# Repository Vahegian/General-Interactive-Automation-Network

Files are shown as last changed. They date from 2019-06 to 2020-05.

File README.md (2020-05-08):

#### Project was moved here from university GitLab.

### General Interactive automation network

With growing number of Internet of Things “IoT” devices almost everything in our homes and offices can be automated or controlled remotely. 
The General Interactive Automation Network “GIAN” is a system that is trying to achieve just that. GIAN uses simple gesture based commands to select and operate devices. Now the system is connected to a robot, which can be operated by user with two simple hand gestures. In the future 5G network can be used to connect 100s of devices to the system, which will allow it to do more complex tasks such as decorating a house or simply kipping it tidy. The system is developed with scalability in mind to allow fast expansion. It currently works with 3 programming languages giving it access to large number of libraries that can be used for connecting to devices running on Python, Java or C++. 
GIAN is not only taking user inputs, it also provides feedback on what it thinks a user is trying to do. Currently the feedback is provided via Java GUI application on PC and LED matrix in real world. 

## [Video](https://cseegit.essex.ac.uk/ce301/grigoryan_v/capstone_project/blob/master/general-intereractive-automation-network/The%20Project/Research%20and%20Files/Files/Genera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) explaining how everything comes together

For more details about developed code and setup process click [here](https://github.com/Vahegian/General-Interactive-Automation-Network/blob/master/The%20Project/Research%20and%20Files/Papers/Final%20Report.pdf)

## This is what I am working on now.


## The System Flow.
<p align="center"> 
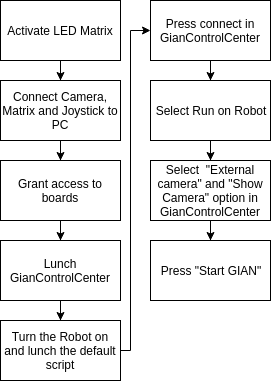
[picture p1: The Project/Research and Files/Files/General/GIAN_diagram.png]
	 
</p>

## The robot selection
<p align="center">
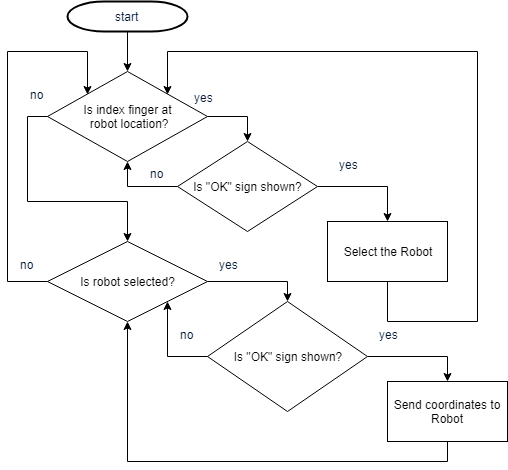
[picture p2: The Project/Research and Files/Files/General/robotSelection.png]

</p>

### INFO

This directory contains two folders. 

"[Summer Research](https://cseegit.essex.ac.uk/ce301/grigoryan_v/capstone_project/tree/master/general-intereractive-automation-network/Summer%20Research)" folder contains files and papers that have been used to come up with a plan for this project. 

"[The Project](https://cseegit.essex.ac.uk/ce301/grigoryan_v/capstone_project/tree/master/general-intereractive-automation-network/The%20Project)" folder contains files and code that are being developed for completing the task.

Most directories will have corresponding "README" files to describe the content of the folder and/or how to use their content. 

## Shortcuts to important directories  

#	1. [3d Models](https://github.com/Vahegian/General-Interactive-Automation-Network/tree/master/The%20Project/Research%20and%20Files/Files/Matrix/3D%20Models)

#	2. [Robot](https://github.com/Vahegian/General-Interactive-Automation-Network/tree/master/The%20Project/JAVA)

#	3. [Arduino](https://github.com/Vahegian/General-Interactive-Automation-Network/tree/master/The%20Project/c%5Cc%2B%2B)

#	4. ['CNN' and master control](https://github.com/Vahegian/General-Interactive-Automation-Network/tree/master/The%20Project/Python)

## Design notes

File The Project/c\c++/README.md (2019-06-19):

### INFO

Master folder contains Arduino script that receives coordinates from pc through Serial communication and transmits them to other 3 Arduinos via I2C communication, also it controls the LEDs of the first matrix. 

The other 3 folders contain Arduino scripts that receive coordinates with I2C and control the LEDs if the coordinates are in the range that they are programmed to control.

Use Arduino IDE to install code on arduino boards. If computer can't access the boards run "arduinopermitions.sh" in linux terminal and try again.

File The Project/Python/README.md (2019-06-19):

## Main Python code is located in "GIAN_files" folder.

## Intro

 

Real-time object detection and classification. Paper: [version 1](https://arxiv.org/pdf/1506.02640.pdf), [version 2](https://arxiv.org/pdf/1612.08242.pdf).

Read more about YOLO (in darknet) and download weight files [here](http://pjreddie.com/darknet/yolo/). In case the weight file cannot be found, I uploaded some of mine [here](https://drive.google.com/drive/folders/0B1tW_VtY7onidEwyQ2FtQVplWEU), which include `yolo-full` and `yolo-tiny` of v1.0, `tiny-yolo-v1.1` of v1.1 and `yolo`, `tiny-yolo-voc` of v2.

See demo below or see on [this imgur](http://i.imgur.com/EyZZKAA.gif)



## Dependencies

Python3, tensorflow 1.0, numpy, opencv 3.

### Getting started

You can choose _one_ of the following three ways to get started with darkflow.

1. Just build the Cython extensions in place. NOTE: If installing this way you will have to use `./flow` in the cloned darkflow directory instead of `flow` as darkflow is not installed globally.
    ```
    python3 setup.py build_ext --inplace
    ```

2. Let pip install darkflow globally in dev mode (still globally accessible, but changes to the code immediately take effect)
    ```
    pip install -e .
    ```

3. Install with pip globally
    ```
    pip install .
    ```

## Update

**Android demo on Tensorflow's** [here](https://github.com/tensorflow/tensorflow/blob/master/tensorflow/examples/android/src/org/tensorflow/demo/TensorFlowYoloDetector.java)

**I am looking for help:**
 - `help wanted` labels in issue track

## Parsing the annotations

Skip this if you are not training or fine-tuning anything (you simply want to forward flow a trained net)

For example, if you want to work with only 3 classes `tvmonitor`, `person`, `pottedplant`; edit `labels.txt` as follows

```
tvmonitor
person
pottedplant
```

And that's it. `darkflow` will take care of the rest. You can also set darkflow to load from a custom labels file with the `--labels` flag (i.e. `--labels myOtherLabelsFile.txt`). This can be helpful when working with multiple models with different sets of output labels. When this flag is not set, darkflow will load from `labels.txt` by default (unless you are using one of the recognized `.cfg` files designed for the COCO or VOC dataset - then the labels file will be ignored and the COCO or VOC labels will be loaded).

## Design the net

Skip this if you are working with one of the original configurations since they are already there. Otherwise, see the following example:

```python
...

[convolutional]
batch_normalize = 1
size = 3
stride = 1
pad = 1
activation = leaky

[maxpool]

[connected]
output = 4096
activation = linear

...
```

## Flowing the graph using `flow`

```bash
# Have a look at its options
flow --h
```

First, let's take a closer look at one of a very useful option `--load`

```bash
# 1. Load tiny-yolo.weights
flow --model cfg/tiny-yolo.cfg --load bin/tiny-yolo.weights

# 2. To completely initialize a model, leave the --load option
flow --model cfg/yolo-new.cfg

# 3. It is useful to reuse the first identical layers of tiny for `yolo-new`
flow --model cfg/yolo-new.cfg --load bin/tiny-yolo.weights
# this will print out which layers are reused, which are initialized
```

All input images from default folder `sample_img/` are flowed through the net and predictions are put in `sample_img/out/`. We can always specify more parameters for such forward passes, such as detection threshold, batch size, images folder, etc.

```bash
# Forward all images in sample_img/ using tiny yolo and 100% GPU usage
flow --imgdir sample_img/ --model cfg/tiny-yolo.cfg --load bin/tiny-yolo.weights --gpu 1.0
```
json output can be generated with descriptions of the pixel location of each bounding box and the pixel location. Each prediction is stored in the `sample_img/out` folder by default. An example json array is shown below.
```bash
# Forward all images in sample_img/ using tiny yolo and JSON output.
flow --imgdir sample_img/ --model cfg/tiny-yolo.cfg --load bin/tiny-yolo.weights --json
```
JSON output:
```json
[{"label":"person", "confidence": 0.56, "topleft": {"x": 184, "y": 101}, "bottomright": {"x": 274, "y": 382}},
{"label": "dog", "confidence": 0.32, "topleft": {"x": 71, "y": 263}, "bottomright": {"x": 193, "y": 353}},
{"label": "horse", "confidence": 0.76, "topleft": {"x": 412, "y": 109}, "bottomright": {"x": 592,"y": 337}}]
```
 - label: self explanatory
 - confidence: somewhere between 0 and 1 (how confident yolo is about that detection)
 - topleft: pixel coordinate of top left corner of box.
 - bottomright: pixel coordinate of bottom right corner of box.

## Training new model

Training is simple as you only have to add option `--train`. Training set and annotation will be parsed if this is the first time a new configuration is trained. To point to training set and annotations, use option `--dataset` and `--annotation`. A few examples:

```bash
# Initialize yolo-new from yolo-tiny, then train the net on 100% GPU:
flow --model cfg/yolo-new.cfg --load bin/tiny-yolo.weights --train --gpu 1.0

# Completely initialize yolo-new and train it with ADAM optimizer
flow --model cfg/yolo-new.cfg --train --trainer adam
```

During training, the script will occasionally save intermediate results into Tensorflow checkpoints, stored in `ckpt/`. To resume to any checkpoint before performing training/testing, use `--load [checkpoint_num]` option, if `checkpoint_num < 0`, `darkflow` will load the most recent save by parsing `ckpt/checkpoint`.

```bash
# Resume the most recent checkpoint for training
flow --train --model cfg/yolo-new.cfg --load -1

# Test with checkpoint at step 1500
flow --model cfg/yolo-new.cfg --load 1500

# Fine tuning yolo-tiny from the original one
flow --train --model cfg/tiny-yolo.cfg --load bin/tiny-yolo.weights
```

Example of training on Pascal VOC 2007:
```bash
# Download the Pascal VOC dataset:
curl -O https://pjreddie.com/media/files/VOCtest_06-Nov-2007.tar
tar xf VOCtest_06-Nov-2007.tar

# An example of the Pascal VOC annotation format:
vim VOCdevkit/VOC2007/Annotations/000001.xml

# Train the net on the Pascal dataset:
flow --model cfg/yolo-new.cfg --train --dataset "~/VOCdevkit/VOC2007/JPEGImages" --annotation "~/VOCdevkit/VOC2007/Annotations"
```

### Training on your own dataset

*The steps below assume we want to use tiny YOLO and our dataset has 3 classes*

1. Create a copy of the configuration file `tiny-yolo-voc.cfg` and rename it according to your preference `tiny-yolo-voc-3c.cfg` (It is crucial that you leave the original `tiny-yolo-voc.cfg` file unchanged, see below for explanation).

2. In `tiny-yolo-voc-3c.cfg`, change classes in the [region] layer (the last layer) to the number of classes you are going to train for. In our case, classes are set to 3.
    
    ```python
    ...

    [region]
    anchors = 1.08,1.19,  3.42,4.41,  6.63,11.38,  9.42,5.11,  16.62,10.52
    bias_match=1
    classes=3
    coords=4
    num=5
    softmax=1
    
    ...
    ```

3. In `tiny-yolo-voc-3c.cfg`, change filters in the [convolutional] layer (the second to last layer) to num * (classes + 5). In our case, num is 5 and classes are 3 so 5 * (3 + 5) = 40 therefore filters are set to 40.
    
    ```python
    ...

    [convolutional]
    size=1
    stride=1
    pad=1
    filters=40
    activation=linear

    [region]
    anchors = 1.08,1.19,  3.42,4.41,  6.63,11.38,  9.42,5.11,  16.62,10.52
    
    ...
    ```

4. Change `labels.txt` to include the label(s) you want to train on (number of labels should be the same as the number of classes you set in `tiny-yolo-voc-3c.cfg` file). In our case, `labels.txt` will contain 3 labels.

    ```
    label1
    label2
    label3
    ```
5. Reference the `tiny-yolo-voc-3c.cfg` model when you train.

    `flow --model cfg/tiny-yolo-voc-3c.cfg --load bin/tiny-yolo-voc.weights --train --annotation train/Annotations --dataset train/Images`

* Why should I leave the original `tiny-yolo-voc.cfg` file unchanged?
    
    When darkflow sees you are loading `tiny-yolo-voc.weights` it will look for `tiny-yolo-voc.cfg` in your cfg/ folder and compare that configuration file to the new one you have set with `--model cfg/tiny-yolo-voc-3c.cfg`. In this case, every layer will have the same exact number of weights except for the last two, so it will load the weights into all layers up to the last two because they now contain different number of weights.

## Camera/video file demo

For a demo that entirely runs on the CPU:

```bash
flow --model cfg/yolo-new.cfg --load bin/yolo-new.weights --demo videofile.avi
```

For a demo that runs 100% on the GPU:

```bash
flow --model cfg/yolo-new.cfg --load bin/yolo-new.weights --demo videofile.avi --gpu 1.0
```

To use your webcam/camera, simply replace `videofile.avi` with keyword `camera`.

To save a video with predicted bounding box, add `--saveVideo` option.

## Using darkflow from another python application

Please note that `return_predict(img)` must take an `numpy.ndarray`. Your image must be loaded beforehand and passed to `return_predict(img)`. Passing the file path won't work.

Result from `return_predict(img)` will be a list of dictionaries representing each detected object's values in the same format as the JSON output listed above.

```python
from darkflow.net.build import TFNet
import cv2

options = {"model": "cfg/yolo.cfg", "load": "bin/yolo.weights", "threshold": 0.1}

tfnet = TFNet(options)

imgcv = cv2.imread("./sample_img/sample_dog.jpg")
result = tfnet.return_predict(imgcv)
print(result)
```

## Save the built graph to a protobuf file (`.pb`)

```bash
## Saving the lastest checkpoint to protobuf file
flow --model cfg/yolo-new.cfg --load -1 --savepb

## Saving graph and weights to protobuf file
flow --model cfg/yolo.cfg --load bin/yolo.weights --savepb
```
When saving the `.pb` file, a `.meta` file will also be generated alongside it. This `.meta` file is a JSON dump of everything in the `meta` dictionary that contains information nessecary for post-processing such as `anchors` and `labels`. This way, everything you need to make predictions from the graph and do post processing is contained in those two files - no need to have the `.cfg` or any labels file tagging along.

The created `.pb` file can be used to migrate the graph to mobile devices (JAVA / C++ / Objective-C++). The name of input tensor and output tensor are respectively `'input'` and `'output'`. For further usage of this protobuf file, please refer to the official documentation of `Tensorflow` on C++ API [_here_](https://www.tensorflow.org/versions/r0.9/api_docs/cc/index.html). To run it on, say, iOS application, simply add the file to Bundle Resources and update the path to this file inside source code.

Also, darkflow supports loading from a `.pb` and `.meta` file for generating predictions (instead of loading from a `.cfg` and checkpoint or `.weights`).
```bash
## Forward images in sample_img for predictions based on protobuf file
flow --pbLoad built_graph/yolo.pb --metaLoad built_graph/yolo.meta --imgdir sample_img/
```
If you'd like to load a `.pb` and `.meta` file when using `return_predict()` you can set the `"pbLoad"` and `"metaLoad"` options in place of the `"model"` and `"load"` options you would normally set.

That's all.

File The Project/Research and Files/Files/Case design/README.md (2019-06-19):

This directory contains images and project files used for designing and building a project "case/frame". 

**The finished product**

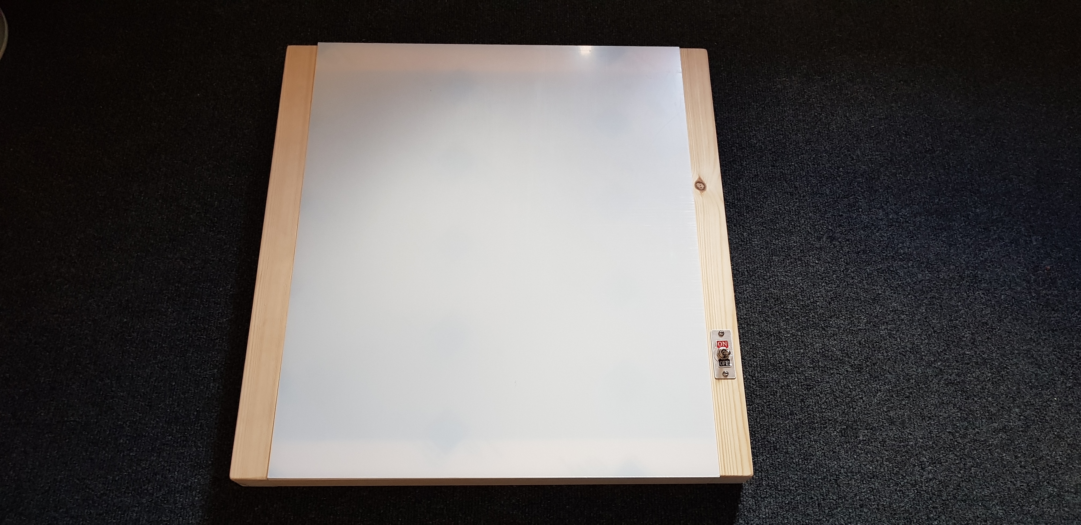
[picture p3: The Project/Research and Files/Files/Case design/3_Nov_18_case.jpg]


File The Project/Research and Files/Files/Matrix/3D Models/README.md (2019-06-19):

**INFO**

This directory contains two folders, which have ".stl" files in them. These files are 3d models designed with "ThinkerCAD". You should be able to open the files in the browser.

**Printing a model**



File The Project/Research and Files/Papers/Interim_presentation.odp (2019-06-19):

## Time Spent Report

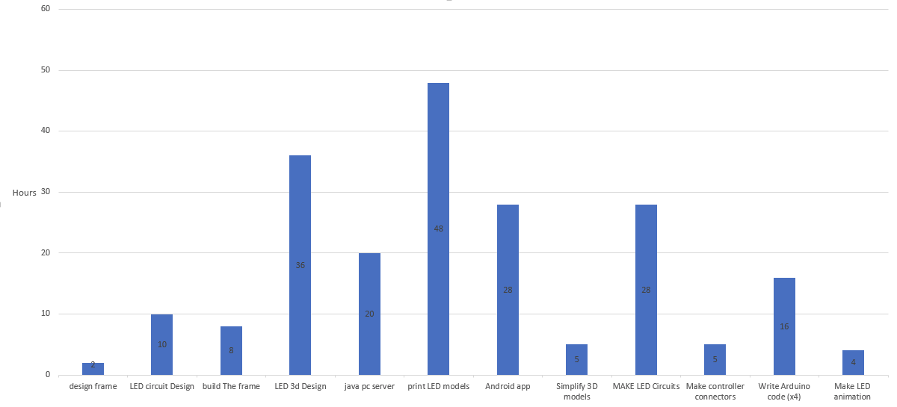
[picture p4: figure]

Total: 210 h.

No-printing: 162 h.

## Jira Report

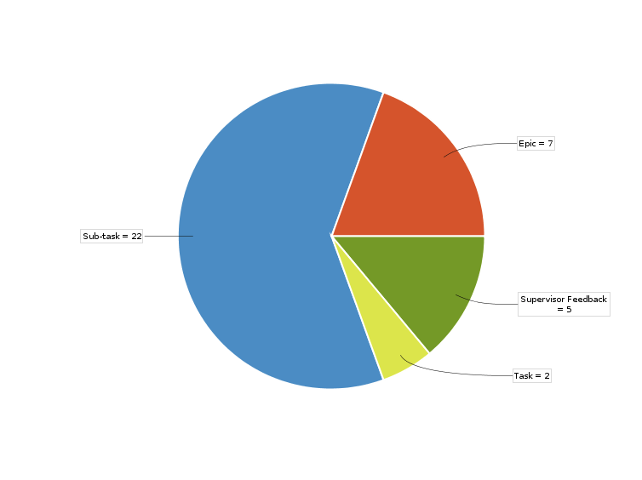
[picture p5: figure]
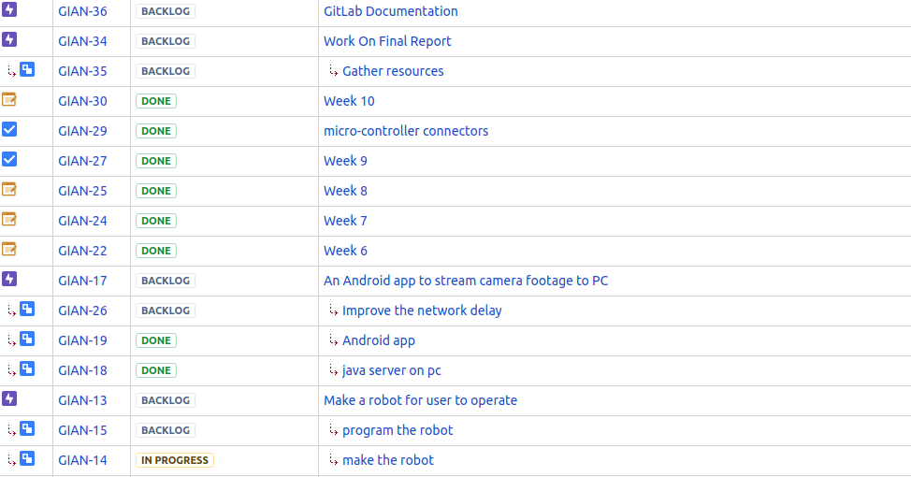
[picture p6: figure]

## GitLab Report

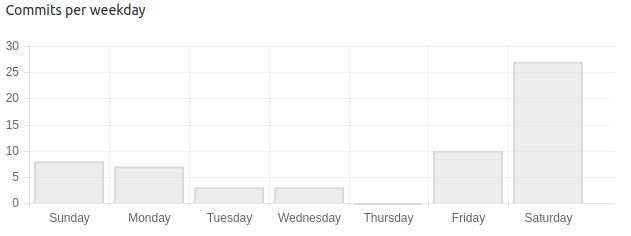
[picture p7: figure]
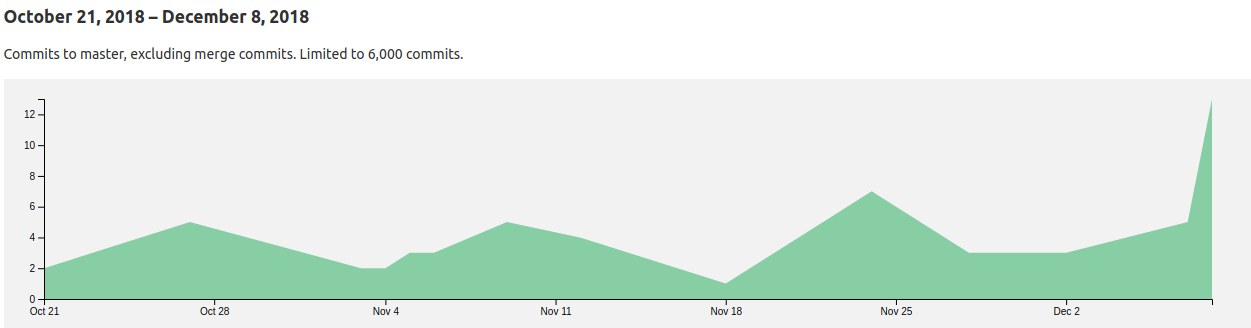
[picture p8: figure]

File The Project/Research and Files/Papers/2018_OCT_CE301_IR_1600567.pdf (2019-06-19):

University of Essex | General Interactive automation network
- 1 -

## Smart home object detection (GIAN System)

Grigoryan Vahe
ID: 1600567
Supervisor: Thakur Manoj
2nd assessor: Reed Martin
Degree course: Computer Systems Engineering
1.Abstract | 2
2.Project goal | 2
3.Background reading | 2
4.Hand gesture detection | 2
5.“Unit” position detection and control | 3
6.LED matrix control | 4
7.Project case | 4
8.Programming languages | 4
9.Testing | 4
10.Project Planning | 5

- 2 -

### 1.Abstract

I present General Interactive automation network (GIAN) System project. In this report I will describe the project goal, background reading and project planning. To provide evidence that this project is possible to do with available technologies, I will build parts of the project in small scale to test them, and if necessary to find better solutions to existing problems.

### 2.Project goal

The goal is to build a system that can recognize hand gestures and operate units (Cars, furnitures) with those gestures. The idea is to have a system like this in a smart home for user to operate the furniture with simple gestures. It will be very costly and challenging to make the full-scale system at this stage, so a small prototype must be built instead. To make sure that the developed code can be used in real envronments It is important to make the system scalable so that more units and communication protocols can be added in the future. Since it is an interactive system the whole thing must run in real time at reasonable speeds and the network must support multiple protocols or must be a combination of different networks. Finally, the system must work with large objects in large environments without significant changes to its structure.
When thinking about previously mentioned features it becomes clear that the project can get very complex and confusing if it is not done
properly, | therefore | while | I | do | the
research I should make sure that the technologies used for building the system are chosen wisely and if necessary are simplified to do only the tasks that the system needs.

### 3.Background reading

Before starting the research, I broke down the project into multiple parts to be researched and developed, which then should be combined into the final thing. The parts are hand gesture detection, “unit” position detection, “unit” control, LED matrix control, product enclosure (case) and programming languages.

I keep a logbook for this project which can be accessed here [1].

### 4.Hand gesture detection

Internet is full of papers describing amazing hand gesture detection technologies. Most of them require multiple sensors and markers to work, which means that the user must have markers on their hand for system to detect the gesture. This method is not good, because it limits where the system can be used, also it requires a lot of code to be written to hardcode marker positions that correspond to gestures. For example, this paper [2] uses “code book algorithm” to process camera input by separating users’ hand from the background for detecting the number of fingers shown in the input. The problem here is that a “haarcascade” for each gesture must be made for OpenCV to detect the gesture. This paper [3] uses “fuzzy clustering” technique for activity recognition. The technique presented in the paper can be adapted to work for my project, but it has one problem, it works with “Microsoft Kinect”, which is a camera unit with additional sensors. It is a problem because for this project I want to use only cameras as sensors, because it will enable the system to work in different environments. The researcher of this paper [4] has also preferred to use camera over secondary input device (Data-Glove) for sign recognition, and they explain the decision with the following “the devices are quite expensive and bring much cumbersome experience to the users”. For those reasons I decided to continue my research focusing on neural networks and machine learning papers that feature only cameras as input devices, because these techniques do not need user coded gestures and additional sensors to work. The following paper [5] describes a software that attempts to control mouse cursor by users’ hand. This relates to my project, because I am attempting to control LED matrix by hand gestures. From the paper it becomes clear that I need some sort of “classification” and “feature extraction” algorithms to detect the hand and track its location. I found this “pose detection” paper [6] from Cornell University library, which is very interesting, because the system uses only camera footage to determine persons pose, but to make it work

- 3 -

a lot of data must be collected and annotated with the correct poses, which is a lot of work for one person. Fortunately, I found this other paper [7] that also uses only camera footage and it comes with built in “classifiers” and “feature extractors”, but instead of annotating the whole pose it works with labels, which are telling what the network is seeing, this approach is less time consuming, thus manageable by one person. The paper describes YOLO (you only look once) method. This method is better at object detection than other object detection techniques, because it scans the footage only once and can find multiple object at once. Other techniques such as R-CNN or fast R-CNN take more time and resources to do the same thing, but they have the advantage of being more accurate. Since my system is supposed to work in real time YOLO is much preferred option for now. I am going to use one camera to detect users hand gestures and another camera to detect the “unit” position. Good quality high definition cameras are expensive, therefore to keep the cost down I might use my smartphone as the second camera. The hardest bit for using YOLO is the installation and data collection processes. To get the YOLO up and running multiple external libraries and drivers must be installed, including GPU drivers and libraries to enhance the performance of the software. Fortunately, the installation processes of TensorFlow [8] and YOLO [9] are describer ferly well on their official web sites.
The data collection means collecting images of people pointing to camera and that of showing “OK” sign, which then must be annotated. Annotating images means creating an xml file for each image that holds data of where the hand is in the image and what gesture it is showing. To create those xml files, I will use a free software “LabelImg” [10]. This software has a graphical user interface, which makes it easier to create xml files by simply highlighting the needed part in the image.

After collecting and annotating some images, a convolutional neural network can be trained using the method described in the YOLO website.
Finally, I will use the trained model to detect gestures from the camera footage and will
display | the | results | using | OpenCV.

### 5.“Unit” position detection and control

For the “unit” I can use a Lajos NXT to build a robot that I can control remotely. For detecting the location of the robot, I can make another YOLO model that recognizes the robot on a grid from a camera input and extracts the coordinates of the robot from the frame. I can also use DEAD Reckoning localization with the robots’ on board odometry, the advantage of this technique is the fact that it is less computationally intensive to perform and can be done by the robot, however it will not work if robots’ position is needed when it is stationary, the opposite is true with YOLO model, and for this reason I decided to use both, so when robot is stationary I will use YOLO and will use odometry when the robot is moving to find its position. Two methods can be used for controlling the robot. Data can be sent in real time, via Bluetooth, for robot to go forwards, backwards, right and left, or coordinates can be sent, based on, which robot will do calculation to figure out where it needs to go from its current position. The second method is preferable, because it does not require robot tracking, so I will use the YOLO model only for detecting the robots’ initial position and then robot will do the rest, allowing more CPU and GPU time for other tasks. This can be useful if in the future more robots are added to the system. In this paper [11] a robot is controlled with gestures as well, but it is not using the YOLO for gesture detection and the robot is controlled by sending directions, instead of locations. From the paper, it is clear that sending directions while the robot is moving introduces delays, because of communication, which leads to inaccurate control. It is Interesting to note that the researchers’ object detection method had 90% accuracy, which is impressive and proves that it is possible to achieve high levels of

- 4 -

accuracy with machine learning techniques.

### 6.LED matrix control

There is a need for making a LED matrix, because user needs to have some sort of feedback from the system to help them intuitively use it. In this case the LEDs of the matrix will show where the hand of the user is pointing. There are many ways for making such matrices, in this paper [12] I found very detailed descriptions of power LED drivers, these methods can apply to my project, even though I am using regular LEDs instead of power once. The implementation of those drivers can get very complex when using large number of LEDs, so I continued my research and found many other methods. Charlieplexing, address registers with controller and multiplexing just to name a few. The matrix is going to be on a 50x50 cm case, so my plan is to have one led per 4 cm, which means that I have to build 12x12 matrix, thus 144 LEDs must be addressed individually. With charlieplexing many LEDs can be addressed with a few controller pins, but it is hard to implement on a PCB and if one of the LEDs stopes working it will cause other LEDs behave incorrectly, for those reasons I will use the next best method, which is multiplexing. This method needs more controller pins, but it is easier to implement, and faulty LED does not affect the other LEDs. To make the job easy I will make four 6x6 LED matrices, where each matrix will have an Arduino pro mini to control the LEDs and communicate with other matrices using I2C communication protocol. 12 pins from the Arduino will be used for controlling the 6x6 matrix (36 LEDs), which means I don’t need to use external address registers because the controller has enough pins, however I must use an external power source because Arduino does not have enough power to control 36 LEDs at the same time. The following Multisim project [P1] shows the circuit design for 36 LEDs.

### 7.Project case

Some sort of enclosure is needed for keeping all the components of the project together and the robot needs to have a space where it can be manipulated. For those reasons a case must be built. The case can be made of wood and it will probably have square shape on bottom and will have a spot on top where cameras can be attached. The LED matrix will be placed on the bottom of the case and it can be cover with acrylic glass to let the light through, and finally the robot will be operated on top of the glass.

### 8.Programming languages

The neural network that detects objects is the crucial part of the system, so the language that has the most flexibility and support, when working with machine learning frameworks, will dominate the system in terms of programming languages. Python with its simple syntax and powerful 3rd party libraries is the choice for this system. Python is good for machine learning, but when it comes to low level programming such as controlling LEDs the programming language C is much better, and it works with Arduino IDE, which I am going to use to program Arduino boards. Java will be used for programming the robot because it has good support libraries for Lejos nxt, which will make the programming process a lot easier. Java might also be used for making an Android app to use the smartphones camera for detecting the position of the robot when it is stationary.

### 9.Testing

For object detection I decided to use the YOLO method, but before I can do that, I need to install drivers for GPU, many 3rd party libraries to support TensorFlow and Darknet, and
finally | use | the | provided | trained
model to test the installation. (More about the installation in the main report). After completing the above steps, I made a simple python script that takes a footage from a web cam passes it to YOLO which then does the prediction on the laptops GPU, and finally it displays the results. The point of doing this was to calculate the time it takes for detection to happen on my laptop. The results were a bit disappointing but acceptable. The program run at 10 fps, after optimizing the code with multiple threads the frame rate went up to around 15 fps.

- 5 -

At this point CPU was usually waiting for the GPU to respond, which means for further performance gain the GPU had to be
replaced | with | better | one, | but | I
think 15 fps will do for this project. The next things that needed to be tested were the Multiplexing with LEDs and I2C communication. To test them I made 3x3 LED matrix and used one Arduino board to control the matrix and another one to choose which led should lit up. The communication between the Arduinos was established via I2C. The results were impressive, almost instant communication was achieved, but to make the matrix work I had to add NPN transistors in to the mix. [P2] (More about the implementation in the main report).

### 10.Project Planning

The system is designed in a way that different parts of it can be developed independently, meaning I can work on different parts of the project even if I haven’t finished working on the others. The benefit of this is the ability to switch tasks when one becomes exhausting, also sometimes a problem in one part of the system can be solved in other part of it, so the development process does not stop when I come across with a difficult problem. This agile approach was carried out during the summer research, the development progress can be found here [13]. I am planning to work the same way to develop the whole system, and I believe I can make good assumption about how long it would take to develop different parts of the project based on my summer work. The following [P4] shows the development process and the relationship between the different parts of the project.
On the right side of the image you can see the task, the number of days for completing the task and number of total hours that will be spent on each task for completing it. On the left side you can find the project flow (meaning the relationship between the tasks), the resource and a percentage showing how busy the resource is going to be for each task. For example, “14%” means the resource
will | spend | that | much | of | avail-

able days for working on the task. The following table [P5] shows how much of
the | task | is | completed | and | how
many days it is going to last.
This table [P3] show the milestones that should be achieved at the specified dates, this information can also be found on project flow diagram [P4].
From that table we can see that two milestones will be achieved before the interim oral examination, first one is the finished LED matrix and second one is that the matrix we be controlled with gestures. The project will be managed with the JIRA [14] instead of Taiga server, which was used over the summer, also all the files and papers mentioned in this report, as well as the project files can be found in this GitLab repository [15].

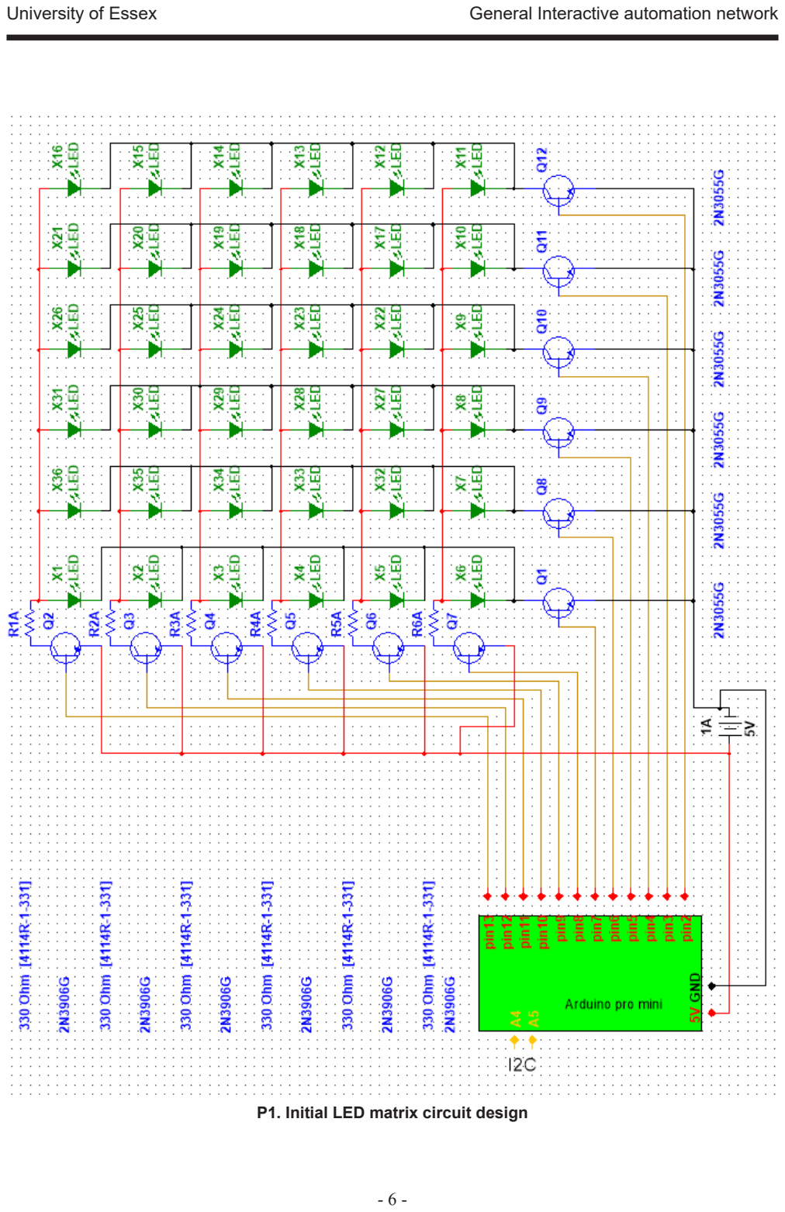
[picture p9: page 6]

- 6 -

P1. Initial LED matrix circuit design

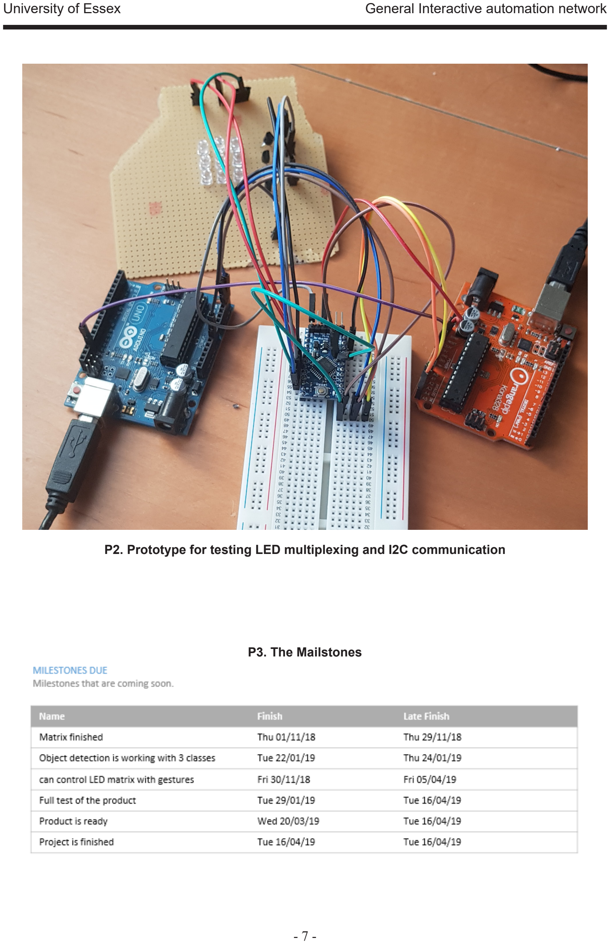
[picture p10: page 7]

- 7 -

P2. Prototype for testing LED multiplexing and I2C communication

P3. The Mailstones

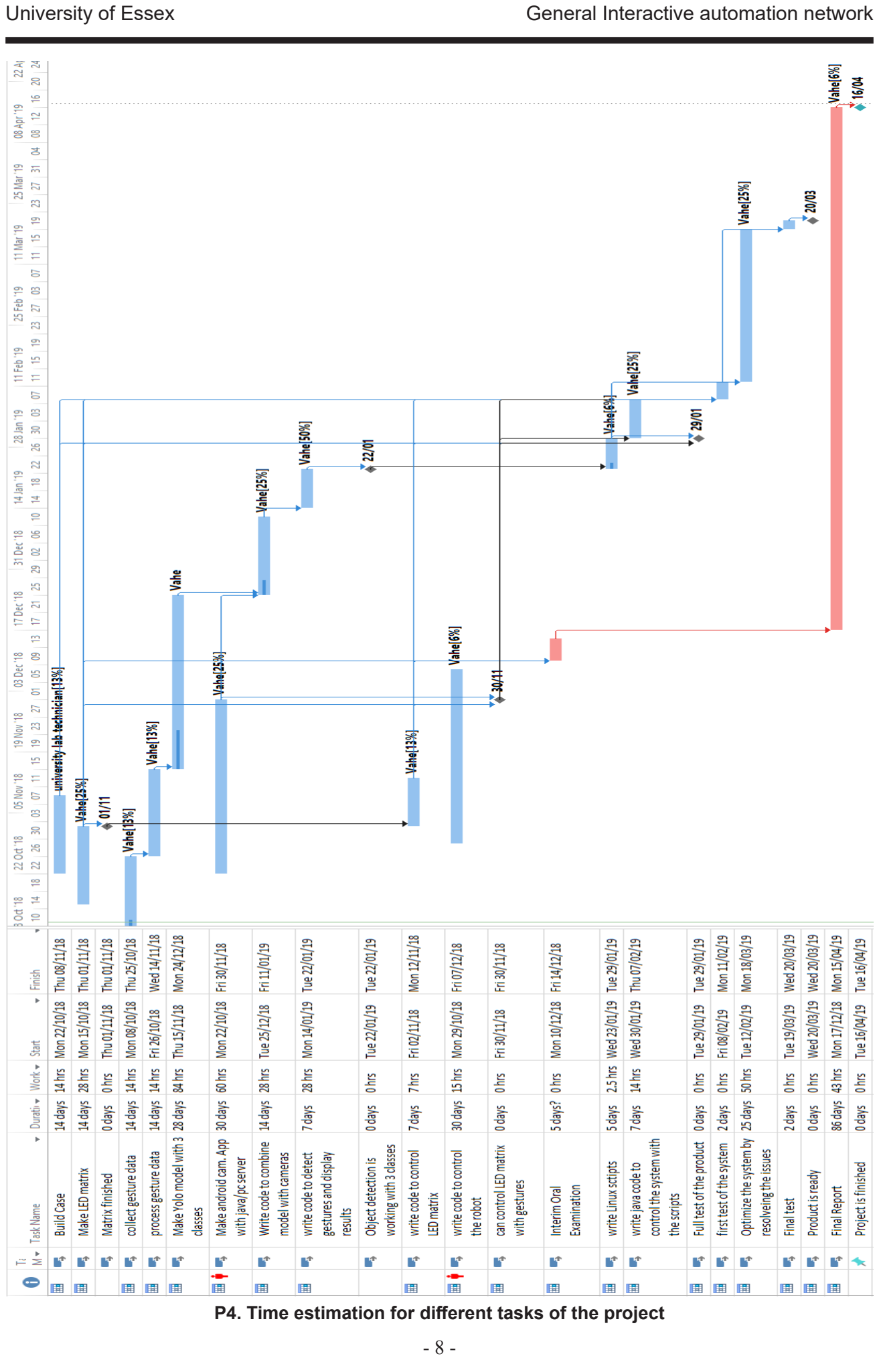
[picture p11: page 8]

- 8 -

P4. Time estimation for different tasks of the project

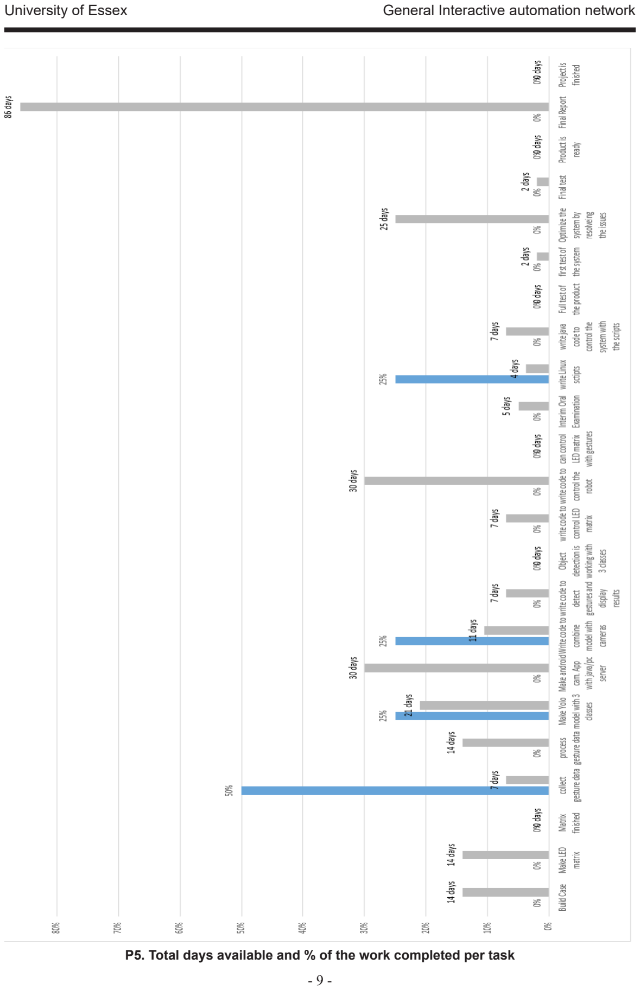
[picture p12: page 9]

- 9 -

P5. Total days available and % of the work completed per task

- 10 -

### References

[1] V. Grigoryan, “Logbook”, OneNote, 2018. [Online]. Available: http://bit.ly/2yf5Fdn. [Accessed: 16- Oct- 2018].
[2] M. Srinivasa, “Implementation of Real Time Hand Gesture Recognition”, International Journal of Innovative Research in Computer and Communication Engineering, 2015.
[3] T. Udhayakumar and S. Anandha Saravanan, “Activity Recognition from Video in Day or Night Using Fuzzy Clustering Techniques”, International Journal of Innovative Research in Computer and Communication Engineering, 2014.
[4] P. Chaudhary and H. Singh Ryait, “Neural Network Based Static Sign Gesture Recognition System”, International Journal of Innovative Research in Computer and Communication Engineering, 2014.
[5] D. Suresh, P. Subash and F. Noorullah Khan, “Computer Intraction Based on Hand Gestures”, International Journal of Innovative Research in Computer and Communication Engineering, 2015.
[6] R. Alp Guler, N. Neverova and I. Kokkinos, “DensePose: Dense Human Pose Estimation In The Wild”, 2018.
[7] J. Redmon, S. Divvala, R. Girshick and A. Farhadi, “You Only Look Once: Unified, Real-Time Object Detection”, IEEE Conference on Computer Vision and Pattern Recognition, 2016.
[8] ”Install TensorFlow with pip | TensorFlow”, TensorFlow, 2018. [Online].
Available: https://www.tensorflow.org/install/pip. [Accessed: 10- Sep- 2018].
[9] J. Redmon, “YOLO: Real-Time Object Detection”, Pjreddie.com, 2018. [Online]. Available: https://pjreddie.com/darknet/yolo. [Accessed: 19- Sep- 2018].
[10] Tzutalin, “tzutalin/labelImg”, GitHub, 2018. [Online].
Available: https://github.com/tzutalin/labelImg. [Accessed: 16- Sep- 2018].
[11] M. Dhabale and A. Kamune, “Gesture Identification Based Remote Controlled Robot”, International Journal of Innovative Research in Computer and Communication Engineering, 2014.
[12] R. AKKAYA and Y. GÜRBÜZ, “Design, Implementation and Comparison of Flyback Type Power LED Drivers with External and Internal PFC in Terms of Harmonics and Power Factor”, International Journal of Innovative Research in Computer and Communication Engineering, 2014.
[13] V. Grigoryan, “Taiga”, Cseetaiga.essex.ac.uk, 2018. [Online].
Available: https://cseetaiga.essex.ac.uk/project/vg16661-object-detection-for-autonomousdriving. [Accessed: 16- Oct- 2018].
[14] V. Grigoryan, “Log in - CSEE Jira”, Cseejira.essex.ac.uk, 2018. [Online].
Available: https://cseejira.essex.ac.uk/browse/PC-27. [Accessed: 16- Oct- 2018].
[15] V. Grigoryan, “general-intereractive-automation-network”, GitLab, 2018. [Online]. Available: https://cseegit.essex.ac.uk/vg16661/general-intereractive-automation-network. [Accessed: 16- Oct- 2018].

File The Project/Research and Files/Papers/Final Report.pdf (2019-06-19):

## General Interactive Automation Network

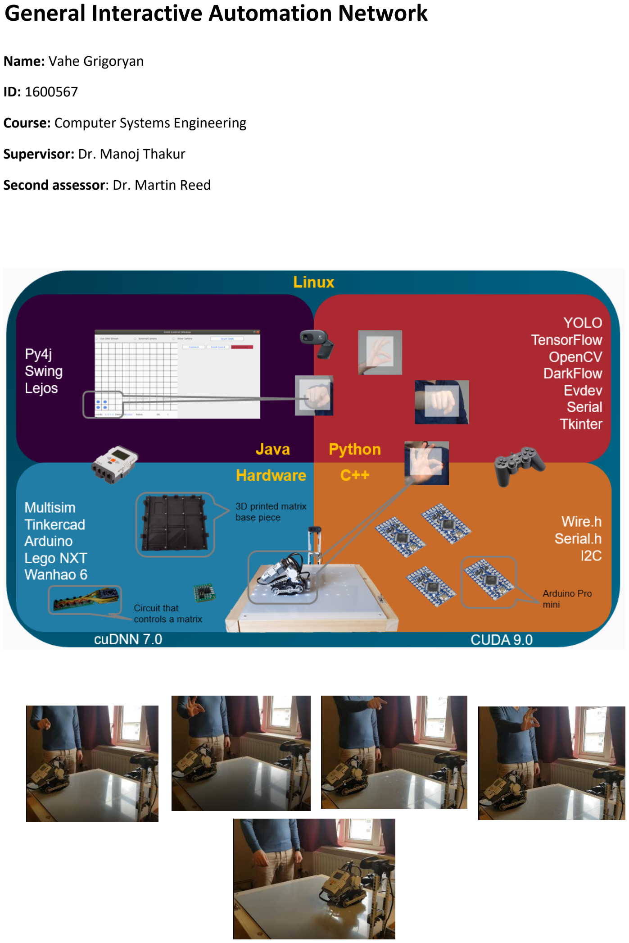
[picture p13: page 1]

Name: Vahe Grigoryan

ID: 1600567

Course: Computer Systems Engineering

Supervisor: Dr. Manoj Thakur

Second assessor: Dr. Martin Reed

## Acknowledgements

It is a pleasure to remind the fine people in the University of Essex for their help.

I would like to express my appreciation to Dr. Manoj Thakur for his guidance and feedback during the course of the project.

A special thanks to Workshop Technician/Toolmaker, Paul Vincent for making a beautiful wooden frame for the project components.

Thank you very much for your guidance and efforts.

## Summary

With growing number of Internet of Things “IoT” devices almost everything in our homes and offices can be automated or controlled remotely. The General Interactive Automation Network “GIAN” is a system that is trying to achieve full home automation, while providing a simple gesture based user interface. GIAN uses simple gestures to select and operate devices with various physical and technical capabilities. A small scale model of the system is developed to test its practicability and limitations. In this report we will discuss the existing legal and ethical issues regarding to similar systems, cover the technologies used for building it and reflect on project planning technologies and methodologies used during the course of the project.

## Table of Contents

## List of Symbols

GIAN – General Interactive Automation Network

(G)UI – (Graphical) User Interface

IoT – Internet of Things

LED – Light Emitting Diode

SDK – Software Development Kit

CPU – Central programming unit

GPU – Graphics processing unit

RAM – Random access memory

OS – Operating System

JVM – Java Virtual Machine

IDE – Integrated development environment

TCP – Transmission Control Protocol

IP – Internet Protocol

USB – Universal serial bus

CNN – Convolutional Neural Network

## 1 The Problem

### 1.1 Description

There are many smart devices produced by different companies, which means in order to use them users have to learn different commands and get used to different user
interfaces | (UI). | According | to | this
“NetworkWorld” [1] article elderly people find it very difficult to use such systems, because of the accessibility and complex UI designs. This issue is an important one because a lot of IoTs are integrated into costumer medical equipment and ordinary home furniture. Being able to easily control such devices can be very beneficial and life saving for many people. Unfortunately there are no such systems that have deep integrations with IoTs with simple user interfaces.

IFTTT [2] is a system that tries to solve this problem, but it is dependent on Google online services and users ability to work with their online system. User has to create an account to use online services with IoT devices implementing “if this than that” logic, for
someone | with | limited | knowledge | in
commuters, this could be a difficult task.

Most solutions in this field use more or less the same approach.

### 1.2 Legal and ethical issues

Having devices developed with different companies raises an issue of getting the rights to integrate a third party software with the one that the company has produced. Likely most
companies | provide | SDKs | (Software
Development Kit) for their product, which can be used to control the product to a certain extent with custom software. Usually some sort of license will be associated with the code developed with a SDK depending on the scale of the integration. It is important to be careful when working with different SDKs to avoid any legal problems.

Having a smart home can be very beneficial in terms of operating home appliances, being more efficient with heating and cooling and more, however there are ethical issues associated with devices tracking residences behaviour. Some of them are storing user data on an online database so that user can have access to their data everywhere they go. In situations like this all the user has is the trust in the company to not sell or use the collected data without their knowledge. If the collected data is misused it could lead to violations of user’s privacy and even to identity theft. It is important to know who stakeholders are and how their privacy can be protected when developing a product that interacts with users and collects data about them.

As stated in this ieee [3] article there are range of technological challenges associated with IoT devices and security is one of them. Hacking an IoT device is interesting to malicious users because of their vulnerability and the variety of information they contain about a user. The main weakness of these devices is the internet connectivity they have, which allows hackers to get access to them and once the device is compromised a lot of private information can be obtained.

### 1.3 Sustainability

Solutions similar to IFTTT depend on online services that require the user to have internet connection, which could be a deal breaker for the user who does not want to upload their information to the internet. To sustain such systems they have to make sure that all components can be synced online and any updates to different parts of the system would not affect the integrity of the whole system, which is of course hard due to external factors.

Ideally an automated home should have a command centre or a small server of a sort that can manage all smart devices while running locally and without needing to be connected to external networks. Sustaining such system is easier, because everything is local and there will be no unexpected updates that could potentially break the system.

## 2 The Solution

### 2.1 Description

The aim is to create a simple gesture based user interface, which can use local networks (eg. Wi-Fi, Bluetooth, wired and more) to communicate with devices that are within the systems reaching range, while not relaying on external online technology.

In the scope of this project a general
interactive | automation | network | was
developed to allow users to control a robot with two hand gestures on a custom made LED matrix that provides useful information about users commands. In this context the robot resembles a sofa or other IoT enabled heavy object, which is operated by the user and the LED matrix is the floor of a room. The other features such as controlling the matrix, connecting to a robot and a smartphone are developed to demonstrate the scalability of the system and its ability to connect to multiple devices and manage communication between them at the same time.

The control method of GIAN can be especially practical when connected to IoTs that are integrated in ordinary objects such as armchairs, tables or other heavy furniture allowing disabled users operate those more easily.

### 2.2 Requirements

The decisions made about what technologies must be used are based on research that is described in the “Initial Report” that can be found here [4].

The system consists of two major parts the software and the hardware. Those parts are made up of many different technologies that come together to provide the underlying support to establish and manage the communication between them. Some of these technologies are inherited from different open source or free software and libraries developed by different universities and organisations.

The following resources are required to setup and run the system.

- Hardware
- Computer
- RAM >= 8 GB (min)
- CPU >= 3.0 GHz (i5, i7
or similar)
- GPU = NVIDIA Card
with compute
capabilities grader
than 3.0.
- OS = UBUNTU 18.0
- Lego NXT
- Arduio UNO
- 3 Arduino Pro Minis
- 3D printer (optional)
- Software
- Nvidia graphics card driver (GPU specific)
- CUDA 9.0 [5]
- Cudnn 7.0 [6]
- Python 3.x.x
- TensorFlow-gpu 1.12
- DarkFlow [7]
- YOLO9000 [8]
- OpenCV 3
- Evdev
- Tkinter
- Serial
- Py4j
- Java
- LejOS
- Py4j
- Arduino IDE
- C/C++
- Serial
- Wire.h

### 2.3 Intellectual property

YOLO is a Neural Network model for object detection, which is built using DarkFlow, by University of Washington. It is trained for 9000 object, but unfortunately it is not trained for hand gestures.

A neural network model used in this project is trained for two hand gestures, but underlying technology is that of darkFlow and Yolo.

### 2.4 Software

2.4.1 Preparing the environment
An appropriate working environment has to be created for the system to work properly.

The very first thing we have to do is to install the GPU driver and CUDA library on a computer. The CUDA is developed by NVidia to optimise their GPUs for machine learning tasks. The installation of CUDA is fairly easy process and is well documented in the official website [5], but a problem might occur, if the GPU driver is installed from the CUDA installer, causing the operating system to not login or computer might not start the OS all together. To avoid this problem the driver can be installed manually. The right driver for a GPU can be found on NVidia web site.

Once CUDA is installed, the Cudnn has to be downloaded and the obtained files have to be placed in the corresponding folders where CUDA is installed. This is important, because this library optimises the GPU for neural networks.

Now we have to install all the python, Java and C/C++ dependencies.

The easiest way to install libraries listed in Requirements section is as follows:

- PIP can be used for installing python libraries except DarkFlow and YOLO (one can install those manually, but it will be easier to clone them from the project GitLab [9]).
- Maven can be used for installing java libraries
- Arduino IDE can be used for installing c/c++ libraries.

2.4.2 Training a YOLO model
The gesture detection happens on computer’s GPU which is achieve by using “DarkFlow” that runs on “TensorFlow GPU” library. “DarkFlow” is a platform that is used for designing neural networks and “YOLO” is a convolutional neural network that is using it and can do real time object detection. The whole design of the network is stored in a “.cfg” file. The file contains blocks of text where each block is a description of a network layer. The “YOLO” model we using has 17 layers 9 of which are “convolutional” layers, 6 are used for “maxpoolling”, one is a “net” layer that describes the network’s size, momentum, channels etc. and the last layer is responsible for producing the results. This layer had to be modified to work for this project. Since we are going to train this network for two objects (“OK”-gesture and “Pointing to camera with index finger”-gesture) we have to specify that the number of output classes is going to be 2 and we have to select an activation function, which in this case is going to be “SoftMax” because we want to have unique outputs.

The network is trained on 900 images where both gestures have equal number of image 450 each. The reason for such small dataset is the data collection and labelling process, which is very time consuming. For every image an “xml” file had to be created that contains the details of where the hand is on an image and what gesture it is showing. No external datasets with this type of labelling were found that could be used in this project. Likely there is a free software “LabelImg” [10] that makes the job of labelling images a bit easier.

The Linux script “trainYolo.sh” was written for training the model. It takes two arguments the first one must be a directory of “xml” files, which are the annotations of the collected images and the second argument is the directory of the images. The images and according “xml” files must have the same name (e.g. “img1.png”, “img1.xml”). By default the script is going to train the model on CPU, which will be painfully long process, to enable GPU the following (--GPU=”1.0”) must be added to the end of the script. The specified number can be anything between 0.0 and 1.0 it just specifies how much of the GPU is to be used.

Even though the dataset is a small one, but the model did perform better than expected, which makes the system usable at this stage with about 90% accuracy.

2.4.3 Python code
The python code is responsible for detecting hand gestures, estimating the hand position,
receiving | commands | from | a | Joystick,
transmitting the coordinates of detected hand and gesture to Arduino and to JAVA virtual machine (JVM).

Since many different tasks have to be programmed to work together we have to make sure that the individual technologies are working great on their own and we have to come up with a structure enabling those technologies to seamlessly work together.

Every task that does something unique is developed as a class and can be easily testes separately if necessary. Every class is written in a file of their own along with some “commented” code to test their various functionalities, in addition to this unit tests are written to test classes when small changes are made to avoid running them separately every time.

The python program is composed of 6 classes one of, which is an organizer class. This class combines the necessary bits from all classes after synchronising them to achieve the desired result. There is a class that opens a camera and captures frames from it on a separate thread, another class takes those frames and using the computers GPU tries to find the hand gesture and its position, the Java and Arduino communicator classes take the estimated data to send them to JVM and Arduino boards accordingly.

If user decides to not use the camera different class can be used for receiving commands from a joystick, in which case the detector and the camera classes will not be used and the hand positions will be obtained from the joystick class.

Finally the organizer class makes sure that the classes that run on separate threads are
synchronised | when | collecting | data,
furthermore it implements a logic that allow users to direct information from one class to the other via hand gestures.

There is another class, which is responsible for starting the other classes in a right order when it is executed. This class is needed because the python code can be started from JVM or it can run by itself, so for each of these cases a different configuration is required. When the class is started from Java code we need to use java communicator class to open a bridge between python and JVM, but when it is ran from console no communication with JVM is needed so the class will not be initialised. This feature is added to make the debugging for python easier, since when it is ran from java the user does not get error messages about python code.

2.4.3.1 More details about the classes
Class | File
OpenCamera | CameraIO.py
Detector | YoloDetector.py
SerialToArduino | arduino_communicator.
py
CommOrg | communication_organis
| er.py
JIO | java_communicator.py
JoystickIO | joystick_communicator.
py
Figure 1 - Python classes and files

OpenCamera class uses “tkinter” library to create dialog box with two camera options for user to select, internal (computer’s built in camera) or an external camera (connected via USB). “OpenCV” library is used for turning on a camera based on the user selection and on a new thread frames are captured from the camera. Finally there is a method called “getFrame” which returns the last captured frame.

Detector class is responsible for taking frames from “OpenCamera” class and doing hand gesture detection from them. In addition to that it also finds the hand’s location on the frame and converts it to (12x12) coordinate space. The constructor of “Detector” class creates necessary thread locks and global variables to get everything synchronised when needed. It also has a setup method that takes an “OpenCamera” object to be used for obtaining camera footage and initialises two threads, one for detecting gestures and one for displaying them on a new window. The class itself extends to “Thread” class, which means it has a “run” method that runs on a separate thread and it is used for finding the position of the user’s hand and converting it to (12x12) coordinate system (For LED matrix).

The YOLO model produces a dictionary when an object is detected. The dictionary contains the label (“gesture type”), the confidence of the network, bottom right and top left coordinates of the hand. We are interested in label and the hand coordinates.

There are multiple ways to convert the hands position to (12x12) coordinate space. In version one of the system a mapping was used, so the width of the image was mapped to values from 0 to 11, which is the x coordinate of the hand and the y coordinate was calculated by drawing a bounding box around the hand and calculating its area. If the area is large it means the hand is close to the camera, the opposite is true if area is small and these values are of course in range 0 to 11. This approach worked quite well, but it had a problem, sometimes the area of the bounding box would get large when the hand is not close to the camera, this would usually happen when the user tried to show the “OK” sign mainly because this sign occupies more space that the “index finger” sign, which makes the system think that the hand is closer to the camera and that affects the experience causing confusions to the users, so a better solution was needed.

The new approach involves dividing the image into 144 pieces where each piece corresponds to a specific coordinate, for example the first piece is(0, 0) and the 144th is (11, 11). The hand cannot fit in one image piece so we have to have an additional logic to determine which
piece | to | choose. | The | method
“chooseTheRightAngle” does this by looking at the hands position and based on to what side the hand is shifted toward a selection is made and the coordinate is returned. For example if the hand is closer to the bottom of the image and is shifted towards right than the coordinates of bottom right piece, which is covered by the hand will be returned. This method works better and is consistent, thus it is more reliable and pleasant to use.

Using the detector requires a lot of resources and it becomes hard to debug other features of the system, this is the reason why a joystick is added to the system.

JoystickIO class allows user to produce coordinates similar to one returned from “Detector” class. This class uses “Evdev” library to listen to joystick events on a new thread, it also has a “getCoord” method that returns last values captured from joysticks x and y axis. The class also has a “transform” method that uses the mapping approach from “Detector” class to fit the joystick coordinates in the range 0 to 11, this method will work fine here because the values produced by the joystick are consistent.

SerialToArduino class opens computer’s serial port (USB/Serial) and looks for an arduino board using “Serial” library. If board is connected it will start a serial communication with it. The class has multiple methods, which allow other classes to transmit coordinates to Arduino boards. The “showCoords” method is the most important one, this method takes hand position and robot’s (can be any other IOT device) position to calculate the coordinates of LEDs that have to be turned on, which are than transmitted to Arduino. The
method | uses | “make_robot_occ_space”
method which is specific to the robot used for this project, but it can be modified to work for other robots with different dimensions. This method is important because we have to show the area that the robot occupies to user so they know if the robot is going to fit in the location they are pointing at.

JIO class enables communication between python and java, it uses “py4j” library to do so.

The way this works is as follows:

- Set of memory locations are reserved
- A Java “Stack” object is stored on the memory
- A Java “Map” object is pushed to the “stack”.
- The Map is then updated from both programming languages

The “py4j” library allows python to work with Java objects.

JIO class just handles the popping and pushing of the map. It has a “pop_from_stack”
method that returns a map object, if no map is present in the stack it returns the last map it popped.

The “push_to_stack” method takes a map object and pushes it to the stack, if there is a map in the stack it replaces it, the stack always has only one map in it.

The “get_jvm” method returns a pointer to current JVM, which can be used for creating java objects and accessing their values.

CommOrg class is responsible for organising the communications between all other classes to accomplish a task given by a user. It has methods that start communication with one or
more | external | devices, | for | example
“comm_arduino_with_robot” method takes coordinates from a robot and sends them to arduino board. The “communicate” method is more advanced because it has access to all connected devices and it can decide what information goes where. By default when system is idling it just updates the map with available information, but when “Detector” or

“JoystickIO” get new coordinates or “JIO” updates the robots position the method will try to update the states of all connected devices to make sure that they are up to date and can provide correct feedback if user is to need it. The communications can be started via “start_communication” method that takes a Boolean, which tells it if the code is started from java or from console and based on it the method creates a new thread for correct communication type and starts it.

The python code with DarkFlow and Yolo can be downloaded from GitLab [11].

2.4.4 Java code
There are 3 programms written in java
GianControlCenter, | GianStream | and
GianRobot.

GianControlCenter is a program for users, it provides a graphical user interface (GUI) that allows users to starts the system simply from the UI. It is also responsible for communicating with “GianStream” and “GianRobot”. The former two are written for smartphones and robots to communicate with the system and the communication goes through the GianControlCenter. It is the top level program that manages everything.

There | are | two | main | packages | in
GianControlCenter “gui” and “logic”. The first package contains all classes that make the graphical interface illustrated in Figure 2. The way code is designed allows different parts of the UI to be modified without affecting the looks or functionalities of other prarts. The “gui” package contains 9 classes 5 of, which are panels that contain different UI components. “GIANControlPanel” makes the top portion of the UI. The 3 radio buttons and the “Start GIAN” button are in this class. The “GIANGridPanel” creates the grid located at the left side of the UI. This is where user’s hand position is displayed. The “GIANInfoPanel” is

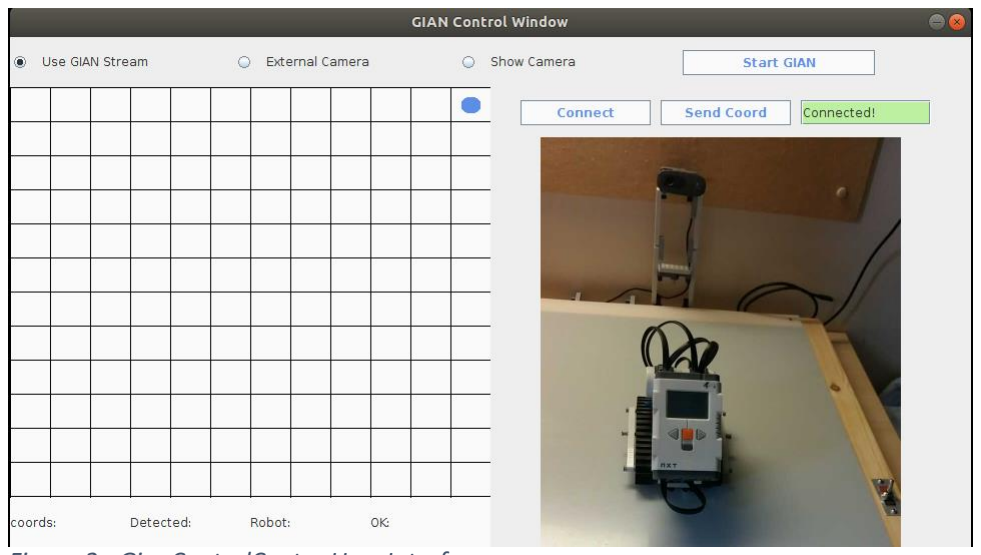
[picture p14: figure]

located right under the grid, this is where more detailed information about hand and robot is displayed. The “GianRobotPanel” contains UI components for connecting and sending coordinates to robot. This panel is located on the right side under “GIANControlPanel”.

The system has a feature that can connect to smartphones and receive images from them. These images are displayed using “Screen” class, which is also a panel. It uses “ImageIcon” class from “java.awt” package to do so. This panel is located under “GianRobotPanel”.

The “Main_Window” class is responsible for taking all previously mentioned panels and putting them in the right places, thus creating the UI window. There is a “custom_objects” package in “gui” that contains two classes, one is used for creating custom designed buttons for this project and the other one is custom colours class with static RGB colours and colour gradients. These classes are used for decorating the panels.

The “logic” package contains 3 other packages
“java_to_py”, | “main” | and | “tcp”. | The
“java_to_py” package contains classes that manage the communication with python code. The “MyStack” class creates the stack we covered when describing the pythons “JIO” class in section (2.4.3.1). The “ProcessCreator” class allows java to call Linux shell commands and is mainly used for starting python scripts. The class has two “lunchScript” methods one that needs only a script location and one that can also have additional arguments for the script. We can use the second method to tell the python if it needs to use the “JIO” class or not by passing “withStack” argument to the script.

The “tcp” package contains two classes “RobotConnector” and “TCPIPServer”. The last one is used for connecting to smartphones via tcp/ip socket and this class opens the socket.

The “RobotConnector” class uses “lejos” library to look for Bluetooth devices that are Lego bricks, once a unit is found the system will automatically connect to it. The class also have methods that provide information about connected robot including robots position, orientation and option. The last one can be anything that robot needs to communicate. For example it can tell if it’s selected for an action or if it’s ready to move. The “sendData” method sends coordinates to robot that are selected by gestures or by other input methods.

The “main” package contains two classes “Main_window_logic” and “StartGianStream”.

The last one is responsible for opening a TCP/IP socket and listening to it for byte arrays on a new thread. On another thread if an array is received the program will try to create an image from it. This part can be modified to do more things for example it can look for other type of data and create different objects. To

Figure 2 - GianControlCenter User Interface

achieve | the | communication | it | uses
“TCPIPServer” class.

The “Main_window_logic” class is responsible for managing interactions between all other classes from lunching the python scripts to updating GUI and processing data received from robot. The class is divided into 5 sections “Robot methods”, “Python communication”, “GUI”, “The Control” and “GianStreamPC”. First, second and the last sections mainly send or receive data with according platform and by using supporting classes. The “GUI” section has a one method “updateSystemInfo” that collects data from the communicators and displays them on computer screen for users. It uses multiple methods from classes located in “gui” package. The “updateHandPos” method from “GianGridPanel” class is used for displaying user’s hand position received from python. It also displays information received from joystick, smartphone and robot so that the user is aware of the states that the external devices are in at that moment.

The “The Control” section has a method “controlRobot”, which takes data from communicators and based on them it decides if user wants to operate the robot or not, and if so what the user wants to do. When the final decision is made it is sent to robot for execution.

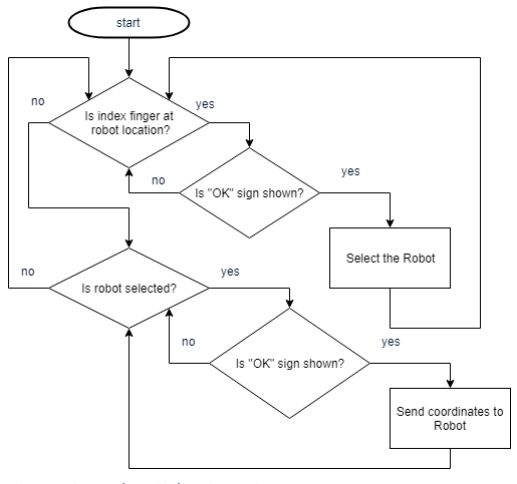
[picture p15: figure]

Figure 3 - Robot Selection Diagram

Since system can understand two gestures the logic of the method goes as shown in Figure 3.

The robot can be controlled from the UI too. There is a text box where user can add coordinates like “10,9” and when “Send Coord” button is pressed the coordinates will be sent to robot, which then will decide if it can go to that location or not. The method that does this is located in “Robot methods” section and is called “sendDataWhenPressed”.

2.4.5 Android Code
GianStream is an android app that enables smartphones to connect and stream their camera footage to a given tcp/ip socket. The app is developed with android studio. The GUI of the app is programmed in xml and contains simple UI elements (Figure 4). It contains two text fields, one button and a TextureView object. The text fields are used for providing servers IP address and port number, which can be obtained from “GianControlCenter”. When “connect” button is pressed the smartphone will start streaming its camera footage to a given server as well as displaying it on TextureView object. There are 4 classes that
make | this | work | “LunchCam”,
“CompareSizeByArea”, “pcSocketClient” and “Main”.

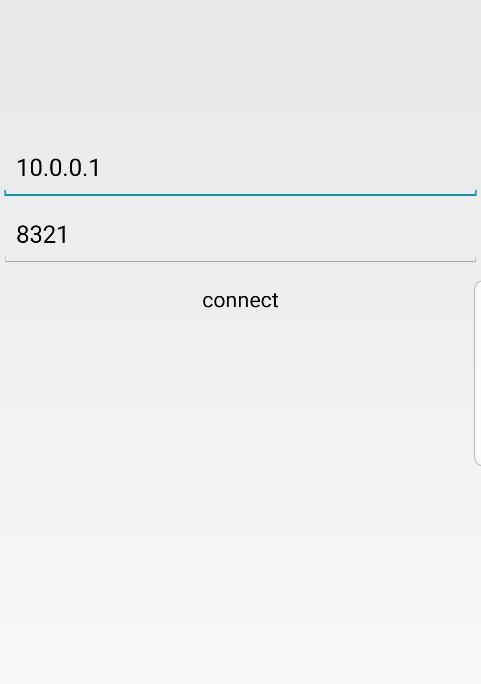
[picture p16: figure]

Figure 4 - GianStream GUI

“pcSocketClient” is used for connecting to a pc, its “makeClient” method is responsible for connecting to one. The IP address and port number have to be supplied to this method. The “streamBitmap” method is responsible for compressing images captured from camera and for sending them to pc.

The “LunchCam” class is using “Camera2API”, which is a complex API, because it uses data pipelines and a lot of API methods have to be used for getting a raw footage from camera. Luckily google provides a sample code for how it is done and this class is heavily based on that sample [12]. The “startPreview” method of the class takes the “TextureView” object and draws the captured frame on it after resizing the frame to fit it on smartphone’s screen. “chooseOptimalSize” method is used for resizing, which uses “CompareSizeByArea” class to compare the size of the image to smartphone’s screen size.

The “Main” class is used for starting the app by creating necessary objects and managing the communication between them. The default “Gradle” solution generated by Android Studio is used for building the app.

2.4.6 Robot code
This code is responsible for controlling the robot’s movements and keeping track of its location. It is divided into 4 sections “Bluetooth
communicator”, | “Path | Planner”, | “Path
Navigator” and “Calibrator”.
Bluetooth | communicator | section | has
“BTReceive” class that enables the Bluetooth communication and waits for incoming requests to connect. When communication is established it waits for incoming data that contains coordinates, after receiving the coordinates it replies with robot’s position, orientation and options information, and then it goes to process the received data. If the data is different than the one it already had the old one gets replaced with the new one. The new data can be obtained from this class via “getCoord” method, which return the
coordinates. | The | class | has | a
“communicateWithPython” method, which attempts to communicate with python code directly. Even though the method works, still there are issues with maintaining the
communication, | which | could | be | an
incompatibility issue with python’s “Serial” library. The communication with java is more reliable, thus it is the default communication method.

Path Planner section has “PathPlanner” class that is responsible for constructing a path for the robot to follow. There are many different techniques for robot path planning “A* search”, “occupancy grid map” and “potential field map” to name a few. The system is already large and complex and to keep the robot code relatively simple a less complex and not very scalable method is used. For this to work we have to make couple of assumptions, we assume that the space where robot is going to be manoeuvred will never change, it will be 12x12 empty grid where robot can freely move in every direction. We restrict the robots ability to make turns at various degrees and limit it to do only 90 degree turns. Whit this assumptions
in | mind | we | create | 2 | methods
“planFromNorthToSouth” | and
“planFromSouthToNorth” these methods are responsible for creating instructions that the robot is going to execute. We need two method because the robot’s perspective changes depending on where it is located and according changes have to be made to the instructions. Both methods use dead reckoning localisation to estimate robots position and plan a path based on pre-programmed rules. The planned path is returned as a list of arrays that contain two values in them. The first value tells the robot what to do, 0 for rotating and 1 for moving. If first value is 0 than the second value tells the degree of the rotation, positive numbers for turning right negative numbers for turning left. If the first value is 1 and the second one is positive it means that the robot has to go forward for given amount, it will do the same but backwards if the second value is negative. The “getPlannedPath” method is used for deciding on, which planning method to use and to do so the method takes 3 arguments, the robot’s current position, the destination coordinates and the robot’s orientation.

Path Navigator section has “PathNavigator” class that can take the instructions generated by path planner and drive the robot according to those instruction. The class has many methods that are responsible for different
robot | functionalities. | The | “followPath”
method is the one that takes the instructions and goes through them to execute the commands, but to get the robot going it uses
two | other | methods | “rotate” | and
“moveForward”. The former two make the robot turn or travel accordingly and they use “findRotationOffSet” and “findTravleOffSet” to correct robots on-board odometery errors. These methods use the formula y = mx − b where x is the amount travelled and y is the offset. To get this formula to work we have to find good values for m and b. To do that we have to take measurements by observing robots behaviour. The Calibrator class can be used for that. This class can find robot’s wheel diameter and track width using the LED matrix, which are useful for setting up the “DifferentialPilot” class (responsible for driving the robot) from “lejos” library. The class also has a method “moveRobotWithIntervals” that makes the robot move forward for 2, 4, 6, 8, 10, 12 and 14 centimetres with intervals that are supplied to it in seconds. We can measure the offset of the robot for each distance manually. By doing so we will have y offset for every x distance and now we can use this information to estimate the values of m and b. To make this process easier a python script “linearfit.py” [13] was written, this script will produce the m and b values. To get it working we have to supply the x and y values to the script. The easiest way to do this is by opening the script and adding the numbers in corresponding lists on lines 10 and 11 (x_list for x distance value and y_list for y offset values). Once we have the m and b values we can substitute them in the according formulas after, which our robot should be more accurate when navigating around.

Finally there is a Main class, which uses methods from previously mentioned classes to control the robot, for instance it will take new coordinates from Bluetooth class, will get robots current position and orientation from odometery and will use “getPlannedPath” method from “path planner” to get the

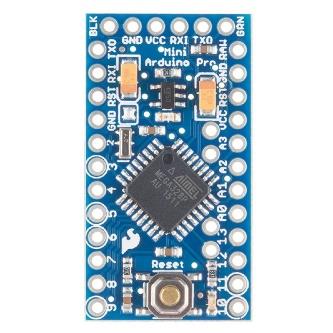
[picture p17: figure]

instructions to supply those to “followPath” method from “path navigator” to get the robot going. It will go over this process again if the received coordinates change.

2.4.7 C/C++ code
There are 144 LEDs (light emitting diodes) that need to be turned on or off. These LEDs are arranged in a 12x12 grid and are used for providing feedback about what system is doing or is expecting user to do. Since using 144 microcontroller pins is not an efficient or practical way of controlling LEDs (controllers with that many pins are very bulky and expensive) a smarter solution had to be made. If we divide the LED grid into 4 parts we will get 4 sections each having 36 LEDs to control, this will simplify the complexity of the circuits.

There are many methods for controlling a lot of LEDs with relatively small number of pins. Charlieplexing and traditional Multiplexing are some of these methods. The first one is more effective in terms of pin saving, but small issues with an LED might cause the whole circuit to behave abnormally, furthermore building the circuit for Charlieplexing is not an easy task. More information about the issues with using

Figure 5 - Arduino Pro Mini

Charlieplexing can be found here [14]. Multiplexing is a better option, because the design is fairly straight forward and it is easier to code, but more pins have to be used. 36 LEDs can be placed in 6x6 grid, meaning we will have 6 negative and 6 positive ports, which means we will need 12 controller pins to individually control 36 LEDs, thus saving 24 pins. Arduino Pro Mini (Figure 5) boards, which are small and efficient have just enough pins to do this. Since there are 4 parts we will need 4 boards. Only 3 of the boards are going to be Arduino Pro Minis, the 4th one has to be an Arduino Uno. This decision was made because the programmer used for Pro Minis did not
correctly | work | with | computers | serial
communication, but Uno worked just fine. So with the current setup we have 1 master Arduino (Uno) and 3 so called slave boards (Arduino pro mini). The master Arduino receives commands from PC and broadcasts them to other Arduinos. The boards use I2C communication to talk to each other. This communication method was chosen, because it allow Arduinos to use their analogue pins for communication rather than digital ones, since those are used for controlling the LEDs. There are 4 Arduino script 3 of which are not very different, because they are only receiving coordinates that need to be lit up. The difference is the limits or the range of the coordinates the board has to react to. Those limits are set in the “loop” method in form of if statements. Each Arduino has different set of limits.

The master Arduino does the most computation, it decides what shape to show and which LEDs must be turned on for achieving that. All starts with it receiving an array from PC that contains 4 values. The first 2 are coordinates for an LED from, which shapes have to be extended, in other words if there is a shape its (0, 0) coordinate has to be the arrays first two values. The third value tells the orientation of the shape it can be a number between 1 and 4, which will correspond to North, South, West or East. The 4th one is the shape option, for example “0” means show finger shape or “non 0” for robot shapes and “4” is for robot shape when robot is not at the location. When robot is selected we will use the command “4” to show the robot shape as a finger location so that user knows that they have selected the robot. Every shape and orientation is programmed in a method of its own, so for example “showFingerLoc” turns 4 LEDs on depending on where the user is pointing. “showRobotEast” method will turn on LEDs to display robots shape facing east and so on. There are 4 additional shapes “G”,”I”,”A” and “N” these letters are displayed one after another to greed the user. The matrix will displays the initial location of robot so the user know where system things the robot is when the system starts.

When looking into these methods it might get a bit confusing and hard to understand what they are doing, because of all “x” and “y” values and coordinates, but everything is quite simple. Every number added or subtracted from “x” and “y” values just tells that we want to go that many LEDs away from the current location and turn them on.

### 2.5 Hardware

2.5.1 LED Matrix

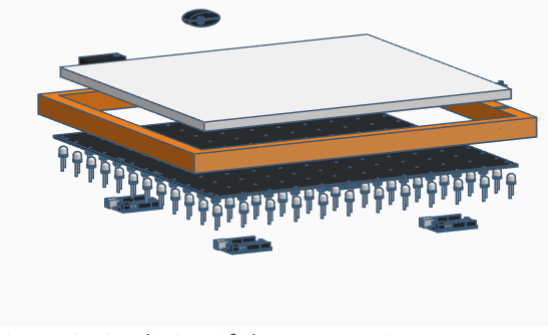
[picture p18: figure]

Figure 6 - 3D design of the LED matrix

As mentioned before the LED matrix is controlled by 4 Arduinos. Since there are 144 LEDs each Arduino has to control 36 of them, this means that each Arduino pin has to be able to turn on 6 LED with their max brightness at the same time. According to the datasheet [15] of the LEDs used in this project the current draw per LED can be about 30mA. The 6 LEDs will draw about 180mA, this means that every pin of the Arduino has to supply 180mA current, however from Arduino website [16] under “Tech Specs” section we can find that Arduino is only capable of supplying 40mA current per pin. This is clearly not enough and given that we have 36 LED we will need a solution that can provide around 1A current. Obviously we have to use an external power supply and to deliver the external power to LEDs we need circuit capable of delivering this power.

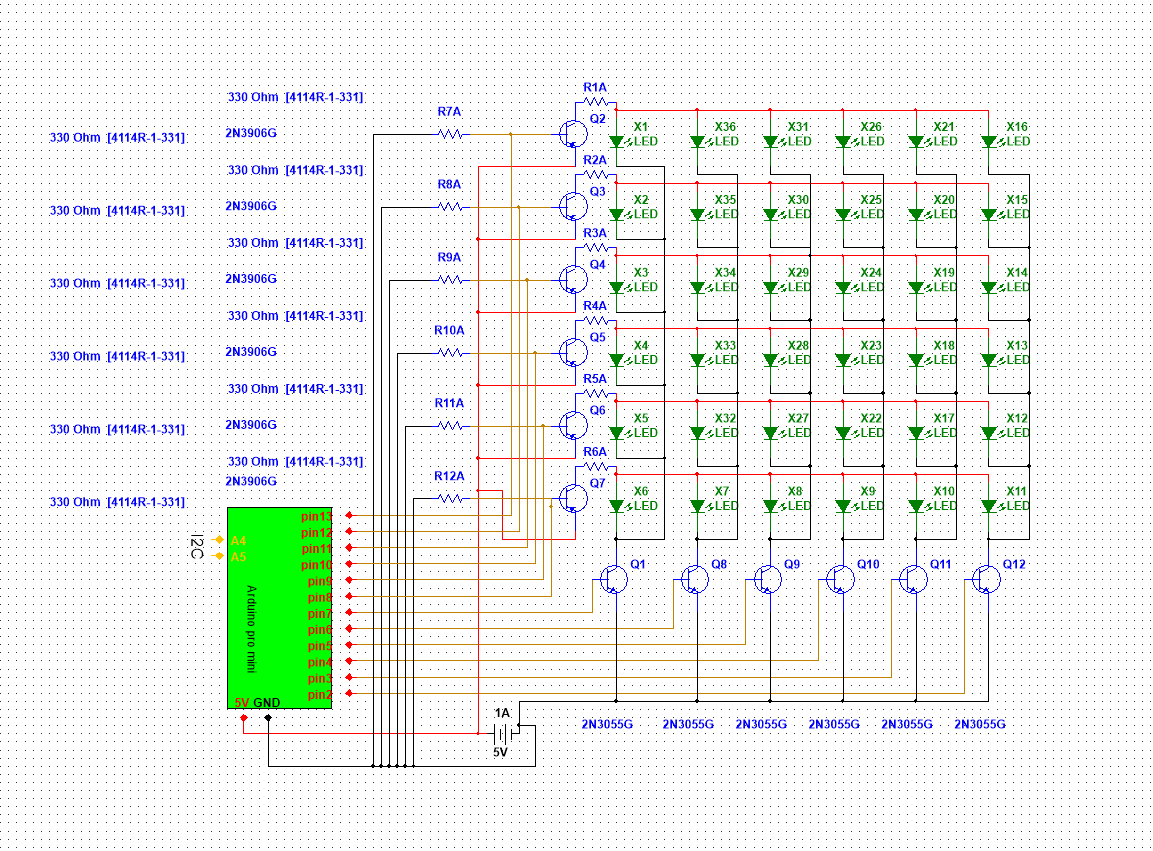
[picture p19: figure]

Figure 7 - 6x6 Matrix circuit schematic

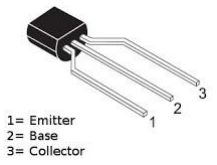
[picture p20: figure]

On Figure 7 we can see the circuit design that is going to be used. It consists of six PNP and six NPN transistors and twelve 330 ohm resistors. The LEDs are placed in a grid that produces 6 columns and 6 rows. The cathodes (positive side) of the LEDs are connected to the columns (6 LEDs per column) and anodes (negative side) are connected to rows (6 LEDs per row).

Figure 9 – physical 6x6 Matrix circuit board

PNP transistors are used for connecting positive side of the power supply to the columns. PNP transistor lets the power through when its base is grounded and restricts it at positive voltages. The Arduino boards can’t turn their pins into grounds (GND), so to create a negative potential at the base we need to connect it to the ground physically. We need to add a resistor to the base after connecting Arduino pin to it to prevent short circuit when Arduino pins supply positive potential to transistor’s base. Another resistor has to be added to the collector pin (pin that the column is connected to) of the transistor to protect LEDs from accidental current spikes. The positive side of the power supply is connected to the emitter of the transistor.

The NPN transistor is activated when the base pin has positive potential and is deactivated when it has negative one. No resistor is needed for this transistor because no danger of damaging the circuit is present since a resistor is already connected to LED row. We mentioned before that Arduinos can’t produce negative potential, and it will not be a problem, because this transistors are activated at certain threshold, which means if we supply positive potential at a level that is below the threshold the transistors will be disabled. On the second page of the transistors datasheet [17] we can see that it activates at potentials above 0.4 volts.

This circuit design first was tested on a breadboard for 3x3 matrix, which performed as expected [18]. After successfully testing the circuit an efficient method had to be found for making 4 of them for each of the 4 6x6 matrices. Aligning 36 LED correctly for soldering wires to them can be very challenging if is not done well. To simplify the process 3D models were created. This models allow LEDs to be easily aligned by having designated spots for them, which makes the soldering process bit easier and less time consuming. The 3D models were created by Tinkercad [19] online 3d designing software

Figure 8 - Transistor and printed with Wanhao D6 [20] printer. Total of 16 pieces were printed.

The 3d models can be found in project GitLab.

There | are | two
configurations | per
model we need two
copies of both. When
all pieces are printed
they can be enforced
together with nuts and
bolts. To keep the
printing times small
the models were printed with fewer layers, which made them fragile, so to keep the models and the circuit safe a case was needed. The case was also designed with Tinkercad, but it was made from wood. To completely eliminate 3d models contact with external objects the frame was covered with Acrylic glass. The frame also houses a switch that can be used for turning the matrix on or off and it has structures where external power source and a camera can be placed. The button on the back of the frame can be used for resetting the boards.

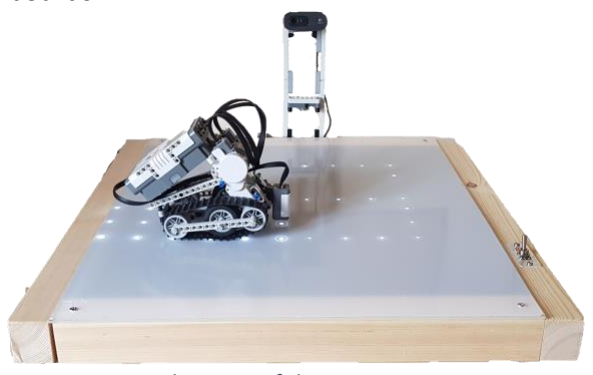
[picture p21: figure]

Figure 11 - Final version of the LED matrix

2.5.2 Robot design

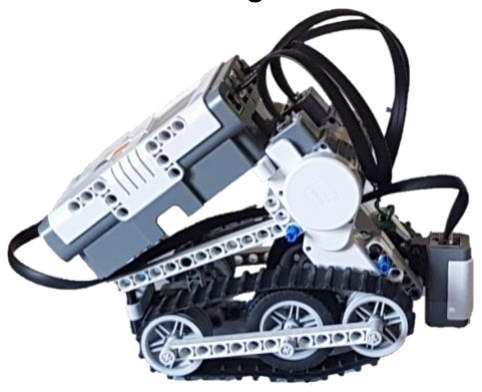
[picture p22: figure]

Figure 12 - The Robot

The robot is built with “LEGO Mindstorms NXT” kit. It has two motors and a light sensor. The sensor is used for calibration we discussed in section 2.4.6. The design of the robot is not very important, because the system does not care what the robot looks like as long as it is calibrated and can plan its navigation path properly. The robot used for demonstrations has 3 wheel on each side for stability and the LEGO brick is on top for easy access see Figure 12.

### 2.6 Control of the system

The compiled versions of the developed programs with the exception of python can be obtained from Gitlab in precompiled form, hopefully making the installation process easier. After successfully installing all necessary components the system should run without problems.

Before the system can be started all external devices (LED matrix, Camera and optionally Joystick) have to be connected to the computer. Next the “arduinopermitions.sh” file has to be executed this will allow Linux to communicate with Arduino. Then we have to make sure that the “GIAN.sh” file is copied to “/usr/GIAN” folder. Once all previous steps are completed the “GianControlCenter” can be lunched. Next the robot needs to be turned on and the default program should be activated. To connect to the robot the “connect” button in “GianControlCenter” should be pressed. When robot is connected the “External camera” and “Show Camera” options can be selected and “Start GIAN” button can be pressed. If everything is done correctly a window will pop up with two options “Detector” and “Joy”. If user wants to use the gestures the “Detector” option should be selected, the other option will start the system using the joystick.

Now user can point at the robot and wait for LED matrix to highlight the area where robot is located, then an “OK” sign can be shown. If the system recognises the sign the robot will make a “beeping” sound indicating that it is selected.

Figure 10 - printed 3D
model piece

After that user can point to other location and if the location gets highlighted with the robot’s shape than user can show the “OK” sign again to move the robot there. When robot moves to new location the process can be repeated.

## 3 What is next

The system can be expanded to support more devices that can add extra gestures and other input methods to it. For example a smart watch can be used for determining the hand position so that the camera can be used for detecting the gestures only or for doing “Spontaneous spatial coupling” [21], a technology that can turn every object into controller, making the system more usable in large spaces.

Finally upcoming 5G network can be used for connecting all devices to the system, which has the potential of improving the communication speeds and reliability of the system.

## 4 Project planning

It was quite a journey from an idea to building a working product. A crucial research was taken during the summer of 2018 to understand and find technologies that can help bring the idea into reality. During this process many different approaches were considered for each part of the project. For example it was decided to use a foam for aligning the LEDs for the matrix, but after discovering the availability of a 3D printer this decision was changed in favour of the printer and the reason was the precision that we could achieve with it. Also “closed palm” gesture was considered for selecting the objects, however later in development stage I realise that the gesture is very similar to the “index finger” gesture, which could cause confusions to neural network leading to wrong predictions. The solution was to replace is with “OK” gesture.

Version control and project planning software were used for all stages of the project.

Taiga (project management software) was used during summer research, but latter during the development “Jira” and “GitLab” were used.

Agile development methodology was used for
project | management, | more | specifically
Kanban.

The Jira software allows us to create different types of issues (Story, Epic, Task, Risk, Bug and feedback) to populate the Kanban board. All issue types were used for managing this project except “Story”. The stories are used when multiple developers are working on the same project and they need to know the context (or scenario) at, which their code or product is going to be used. Since only one person is developing the system there is no need for user stories.

The project was divided into multiple epics and each epic had multiple tasks and later in development cycle Bugs and ricks associated with it. When all tasks of an epic were completed the epic was considered done and was moved to appropriate column on the board. Figure 13 illustrates the quantity and types of issues used in this project.

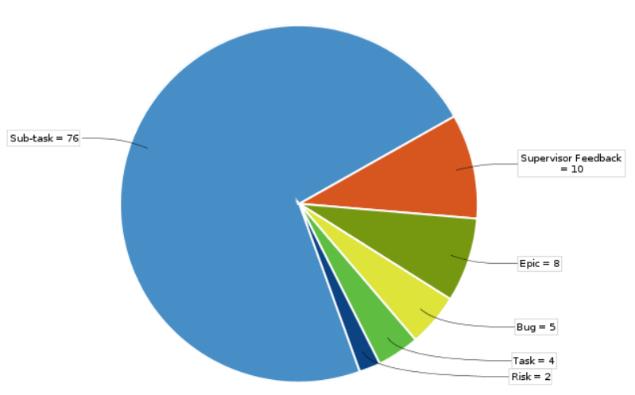
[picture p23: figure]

Figure 13 – Pie Chart: Used JIRA issue types

From the chart we can see that total of 8 Epics were used. The Epics were for JAVA code, Python code, c/c++ code, LED Matrix, Robot and android app. The other two Epics were used for updating GitLab documentation and for working on the report. We can also see that there were 76 sub-tasks this is the total number of tasks created for all Epics. It is worth noting that two Epics are still active, meaning that the number of sub-task might increase over time. There were 2 risks taken for optimising the gesture detection code. Those were risks because a lot of time was needed for completing the optimisation and the results might have not been significant, but fortunately it paid off with significant improvements in performance.

There were regular meetings with project supervisor to discuss the progress of the project and in addition to this supervisor feedbacks were added to the Kanban board. If any suggestions were made in those feedbacks, according changes or modifications were made to test them and the results were shared with the supervisor.

GitLab was used for version control. The developed designs, files and code were stored in there along with technical documentation to make sure that safe backup of developed content is available if it is to be needed. Figure 14 shows the GitLab activity throughout the system development. From the graph we can see that there were active contributions and updates during the development period with total of 154 commits to the repository.

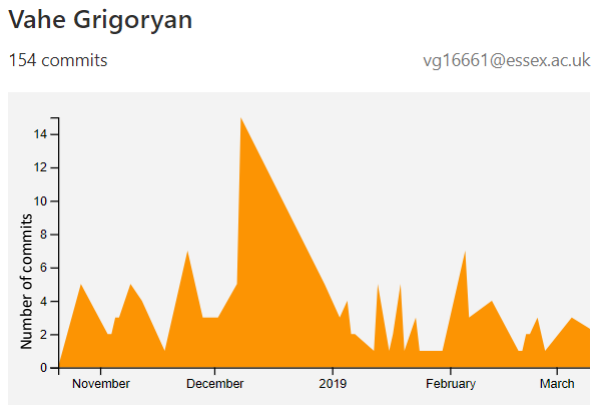
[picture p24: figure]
Number of commits

Figure 14 - Git commit history

## 5 System Testing

The developed system can be used for operating a robot on a constant environment, but many issues are still present, which can be frustrating for someone who does not know how it works and where the problem might be coming from. A care was taken to make the system as user friendly as possible in a given amount of time. For example a graphical user interface was developed to make the interactions with the system easier and joystick was added to the system for users to familiarise themselves with the system using more traditional input method before using hand gestures. Even with the improvements some individuals did not find the system very intuitive, because there was a lag forcing user to wait for system to catch up, but mainly positive reactions were received when joystick was used.

The system has many parts that communicate with each other, so the lagging could potentially be caused by any of them. To figure out the source of the problem we had to reproduce the issue using debugging mode on java and python. Unfortunately reproducing the problem when the codes are run separately was not possible so a different method had to be used. A code was added to python to produce files that contain debugging information. Now we can run system the usual way while getting debugging information about java and python at the same time. It appeared that the problem was caused by “py4j” library, but further investigation showed that the GPU might be causing the real issue. The GPU of the computer that was used for the demonstration had only 2 GB of RAM, which was quickly flooded with data and when system started introducing unnecessary delays it interrupting python to java communication leading to errors with “py4j”.

The lag issue can be solved if faster computer with better GPU is used or the CNN model can be stored on cloud for better performance, but this will mean that the system will have to communicate with a database, which can become an ethical issue.

Overall the system is functional, but many improvements to the speed and scalability have to be made before it can become truly useful in large environments.

## 6 Conclusions

With the expectations of the project fulfilled to a significant quantity, it will be safe to conclude that all desired features of the system were implemented successfully with available resources.

The Idea was to build a system that is not connected to the internet and can control IoT devices with hand gestures. The developed product can do everything that was planned and it also supports an additional input method, a joystick, giving users a choice between traditional and gesture based controls.

A matrix containing 144 LEDs was built, which is controlled with 4 arduino boards. The boards communicate with PC where Python code
sends | them | commands | based | on
Convolutional Neural Network’s predictions. The predications are also shared with Java code, which displays them on computer screen via GUI and sends user commands to a robot. The robot plans a path and navigates it on the LED matrix based on received data, which reflects what user wanted to do with the robot.

In the report we described the technologies used in each part of the system, while justifying the choices, we discussed agile project planning that was used throughout the project and finally we demonstrated the extent to what the system was able to deliver the promised result with system testing.

All developed files and more details about the project can be found in the GitLab [9] repository.

## 7 References

[1] F. Paul, “Why IoT for seniors is a lot tougher than it looks,” [Online]. Available: http://bit.ly/2KdSxhj. [Accessed 31 03 2019].
[2] “IFTTT website,” [Online]. Available: https://ifttt.com/. [Accessed 14 04 2019].
[3] A. Banafa, “Major Challenges Facing IoT,” IEEE.org, [Online]. Available: bit.ly/2GwGfN9. [Accessed 10 04 2019].
[4] V. Grigoryan, “Initial Report,” [Online]. Available: bit.ly/2GBPxr9. [Accessed 10 04 2019].
[5] “CUDA download Page,” NVIDIA, [Online]. Available: https://developer.nvidia.com/cuda-90-download-archive. [Accessed 04 03 2019].
[6] “Cudnn download Page,” NVIDIA, [Online]. Available: https://developer.nvidia.com/cudnn. [Accessed 04 03 2019].
[7] Trieu, “DarkFlow-GitHub,” GOOGLE, [Online]. Available: https://github.com/thtrieu/darkflow. [Accessed 04 03 2019].
[8] J. Redmon, “YOLO v2,” [Online]. Available: https://pjreddie.com/darknet/yolov2/. [Accessed 04 03 2019].
[9] V. Grigoryan, “GIAN-GitLab,” [Online]. Available: https://cseegit.essex.ac.uk/ce301/grigoryan_v/capstone_project. [Accessed 04 04 2019].
[10] T. Lin, “LabelImg-Github,” [Online]. Available: https://github.com/tzutalin/labelImg. [Accessed 06 04 2019].
[11] V. Grigoryan, “Python-GitLab,” [Online]. Available: http://bit.ly/2I1V4Jw. [Accessed 05 04 2019].
[12] “Camera2Basic - API Sample,” Google, [Online]. Available: https://github.com/googlesamples/android-Camera2Basic. [Accessed 18 04 2019].
[13] V. Grigoryan, “linearfit.py-GitLab,” [Online]. Available: http://bit.ly/2UbjGRw. [Accessed 10 04 2019].
[14] “Charlieplexing vs. tradutional multiplexing,” IPFS, [Online]. Available: bit.ly/2Zloh7u. [Accessed 10 04 2019].
[15] “Technical Data Sheet White LED,” Everlight, [Online]. Available: bit.ly/2UCNV90. [Accessed 14 04 2019].
[16] “Arduino pro mini Specs,” Arduino, [Online]. Available: https://store.arduino.cc/arduino-pro-mini . [Accessed 14 04 2019].
[17] “S8050 NPN transistor datasheet,” UTC, [Online]. Available: http://media.nkcelectronics.com/datasheet/s8050.pdf. [Accessed 14 04 2019].

[18] V. Grigoryan, “3x3 LED matrix test,” [Online]. Available: bit.ly/2KEo8sw. [Accessed 14 04 2019].
[19] “Tinkercad,” AUTODESK, [Online]. Available: https://www.tinkercad.com/. [Accessed 14 04 2019].
[20] “Wanhao D6 (3D printer),” WANHAO, [Online]. Available: bit.ly/2PahXeg. [Accessed 14 04 2019].
[21] C. Clarke and H. Gellersen, “Gesture control tech turns any object into a TV remote,” Lanchester University, [Online]. Available: bit.ly/2GsQcem. [Accessed 16 04 2019].

## 8 Appendix

Figure 15 - 6x6 LED Matrix circuit schematic

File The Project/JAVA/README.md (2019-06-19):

**INFO**

## GianControlCenter

You can compile the code located in "src" folder or use "GianControlCenter.jar" to lunch the software. Use this software to start the system.

## GianStream App

To use the GianStream, please install the “GianStream.apk” file from “GianStream App/APKs” folder on an Android smartphone and lunch it. 

On a PC lunch “GianControlCenter.jar” file from “GianControlCenter” folder.

You can type “java -jar GianControlCenter.jar” on LINUX Terminal to lunch the software. 

Make sure that both devices are connected to the same network.

Select "Use GianStream" option and follow the instructions. 

## GianRobot

Download "leJOS_NXT" library from LEGO website.

Make sure it is in the same folder as Main.java file.

Turn the NXT on and activate the Bluetooth

Open a linux terminal in the folder where the Main.java and flashTheRobot.sh files are located.

Type "./flashTheRobot.sh" in terminal to install the code on robot.

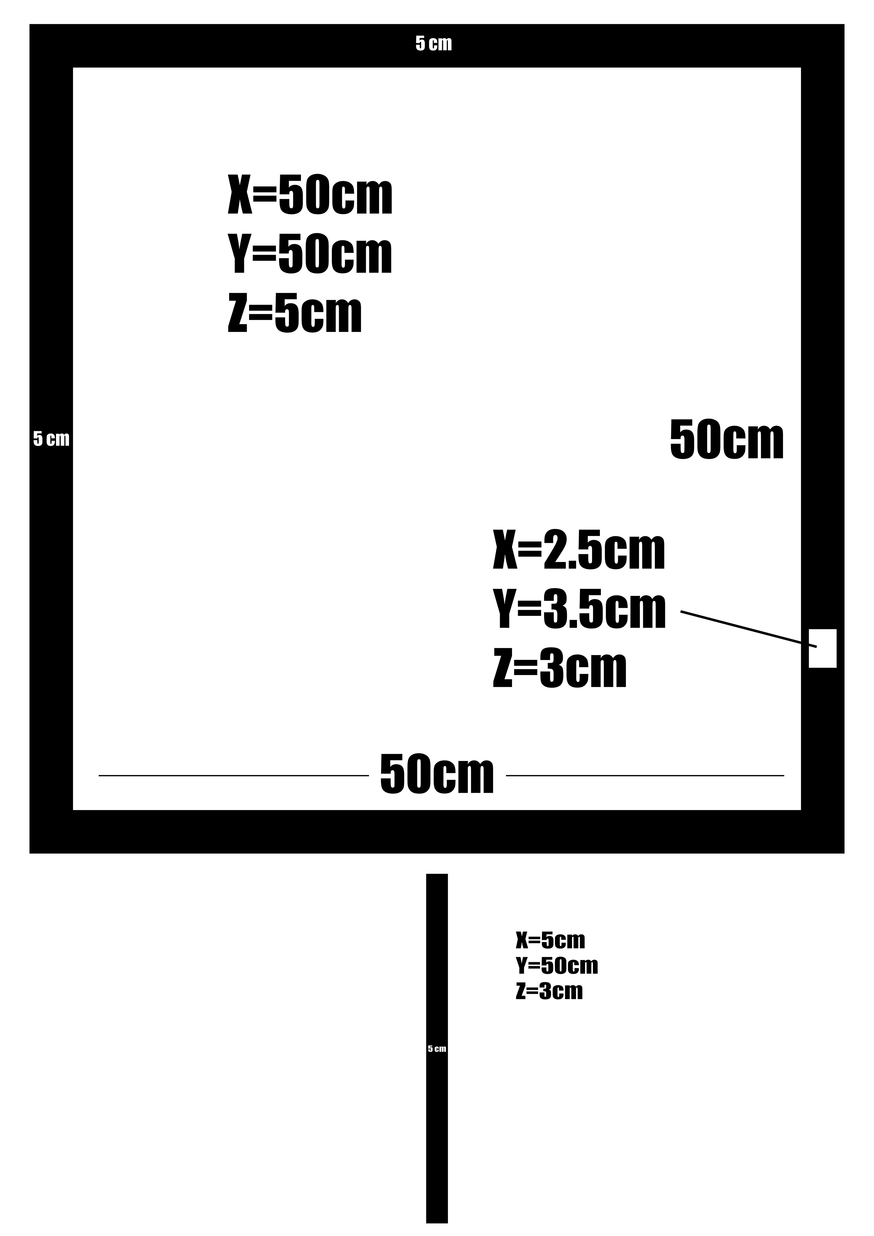
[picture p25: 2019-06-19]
The Project/Research and Files/Files/Case design/box design combo2.png

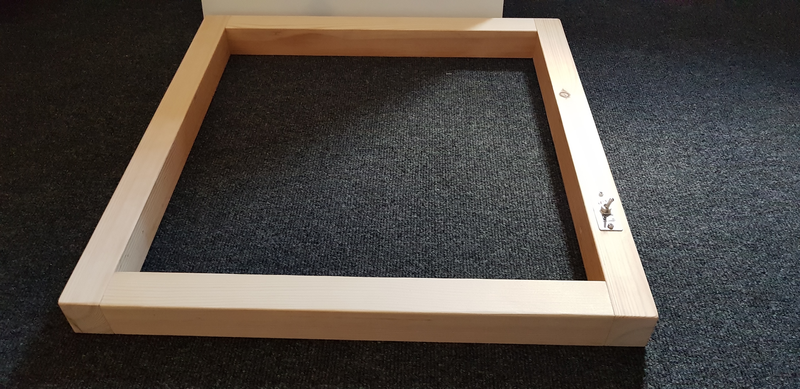
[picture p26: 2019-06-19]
The Project/Research and Files/Files/Case design/3_Nov_18_case2.jpg

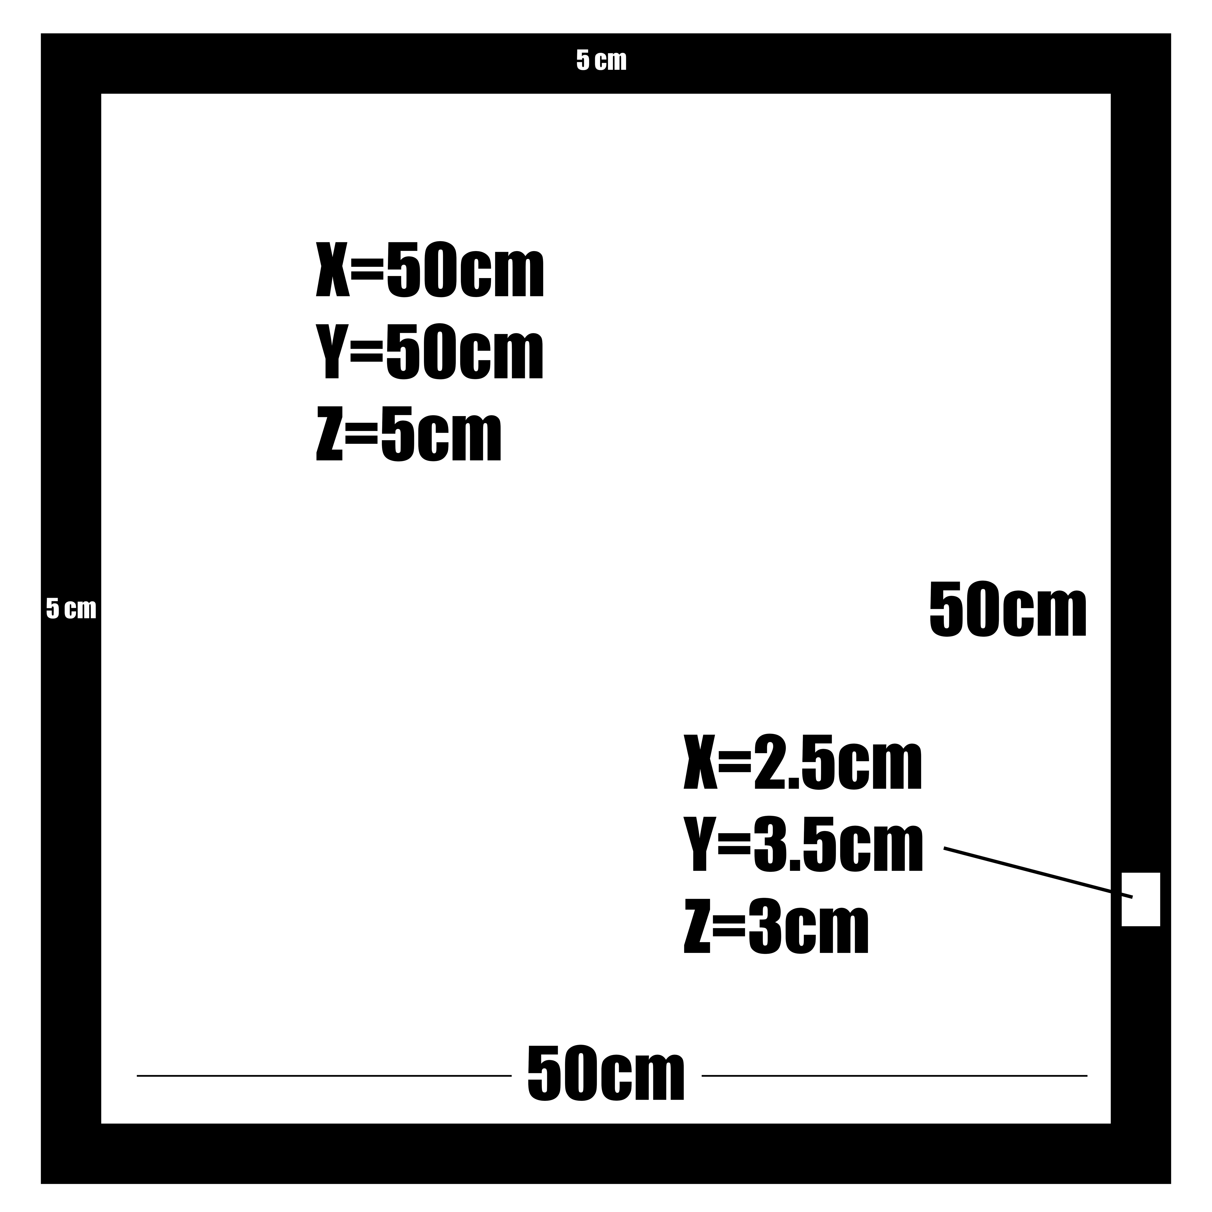
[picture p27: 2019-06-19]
The Project/Research and Files/Files/Case design/box design top.png

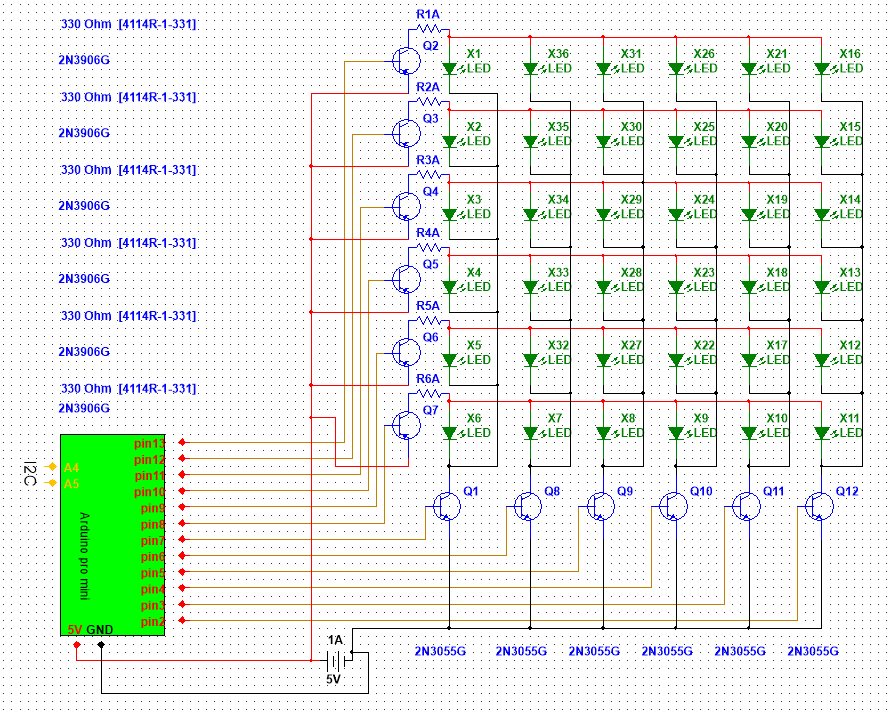
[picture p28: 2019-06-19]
Summer Research/pics/LED shot.PNG

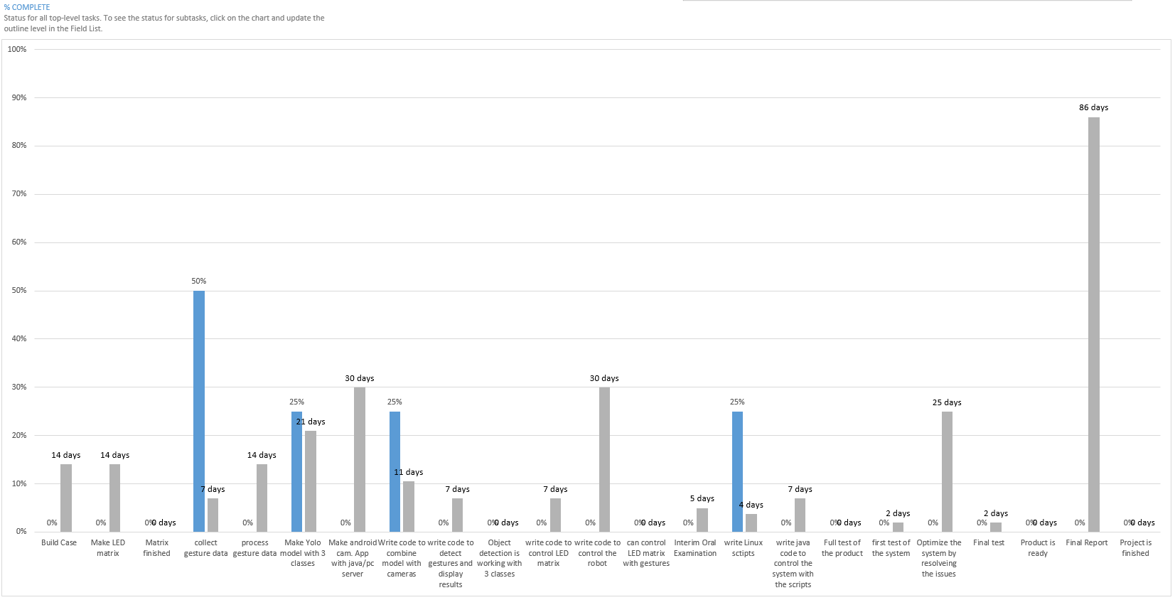
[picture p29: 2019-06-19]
Summer Research/pics/daysvscomplete.PNG

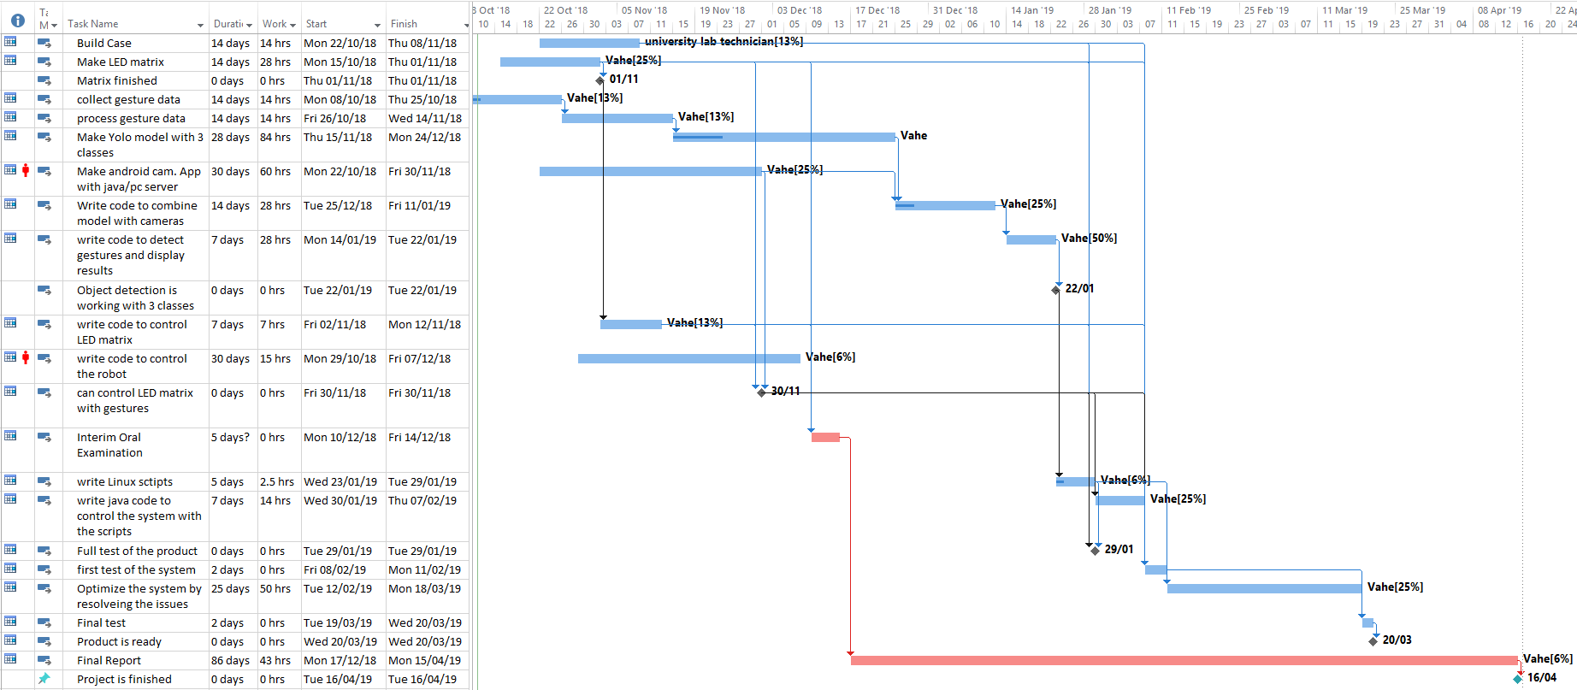
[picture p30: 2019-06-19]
Summer Research/pics/flow.PNG

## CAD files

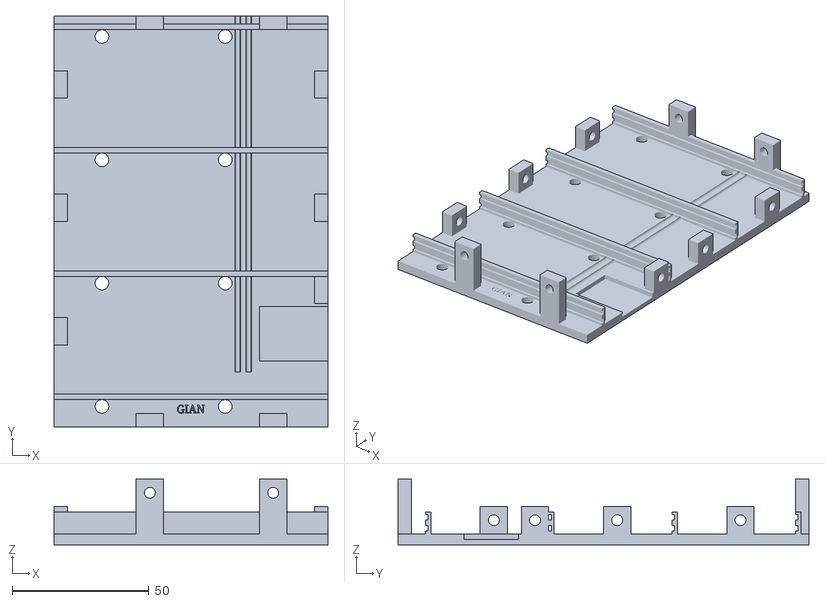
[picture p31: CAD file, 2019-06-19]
The Project/Research and Files/Files/Matrix/3D Models/Type1/LED BASE12.stl
100.0 x 150.0 x 24.0

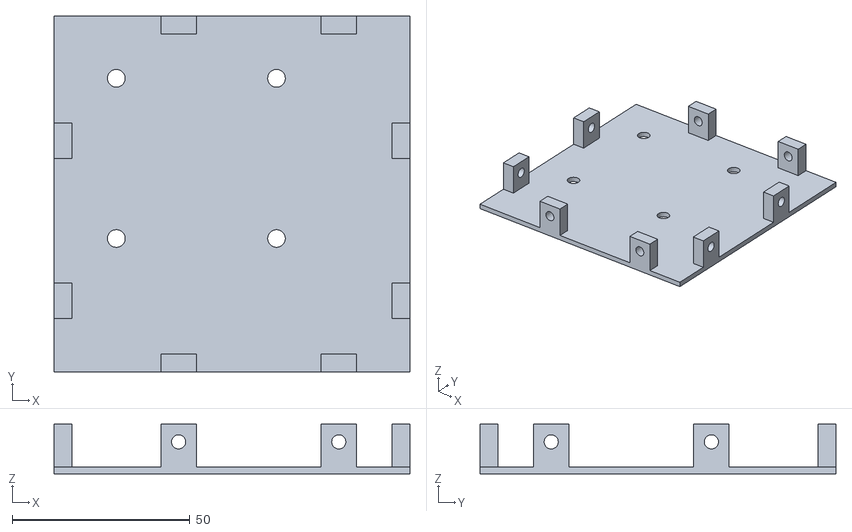
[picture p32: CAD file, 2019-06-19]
The Project/Research and Files/Files/Matrix/3D Models/Type1/Simplified/LED 14.stl
100.0 x 100.0 x 14.0

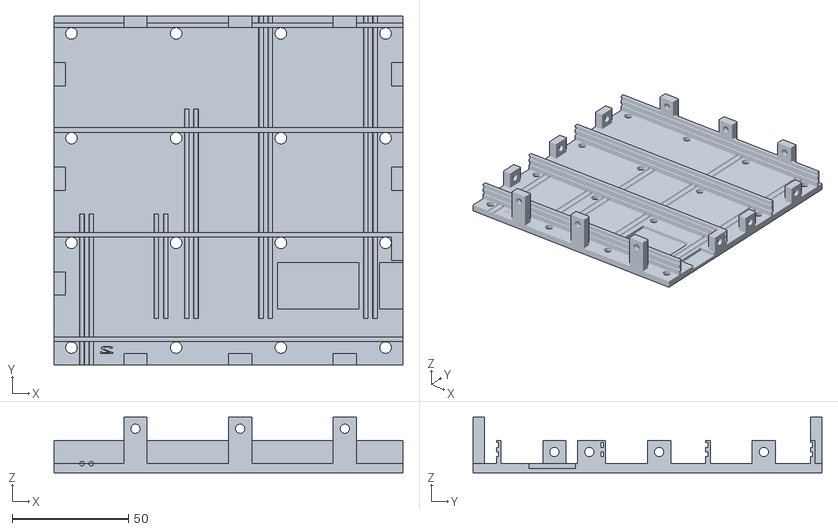
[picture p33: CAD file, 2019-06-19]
The Project/Research and Files/Files/Matrix/3D Models/Type2/LED BASE21.stl
150.0 x 150.0 x 24.0

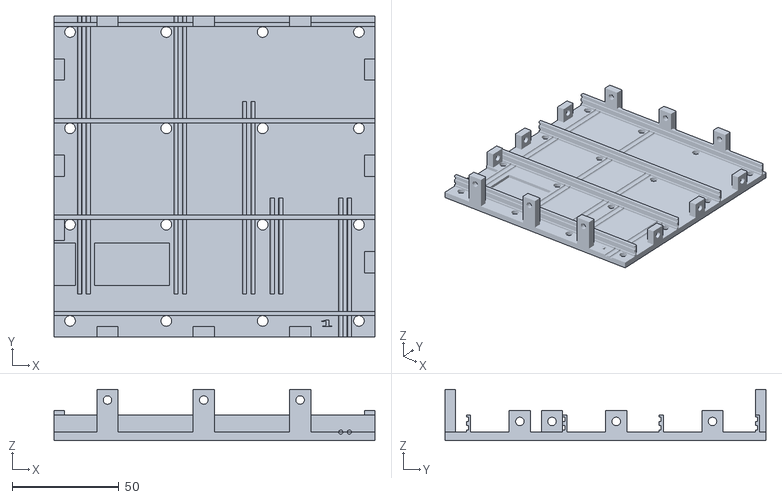
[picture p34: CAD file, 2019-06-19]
The Project/Research and Files/Files/Matrix/3D Models/Type1/LED BASE11.stl
150.0 x 150.0 x 24.0

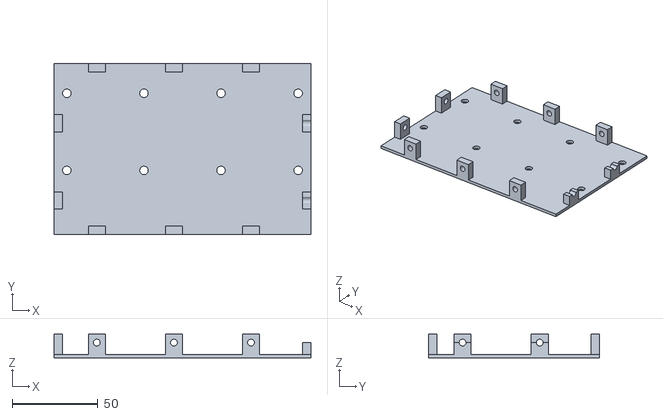
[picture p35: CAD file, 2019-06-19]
The Project/Research and Files/Files/Matrix/3D Models/Type1/Simplified/LED 13.stl
150.0 x 100.0 x 14.0

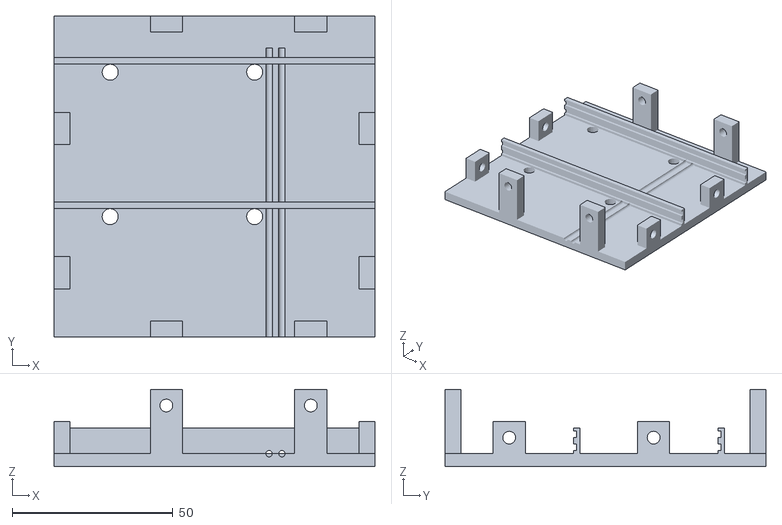
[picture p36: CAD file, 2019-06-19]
The Project/Research and Files/Files/Matrix/3D Models/Type1/LED BASE14.stl
100.0 x 100.0 x 24.0

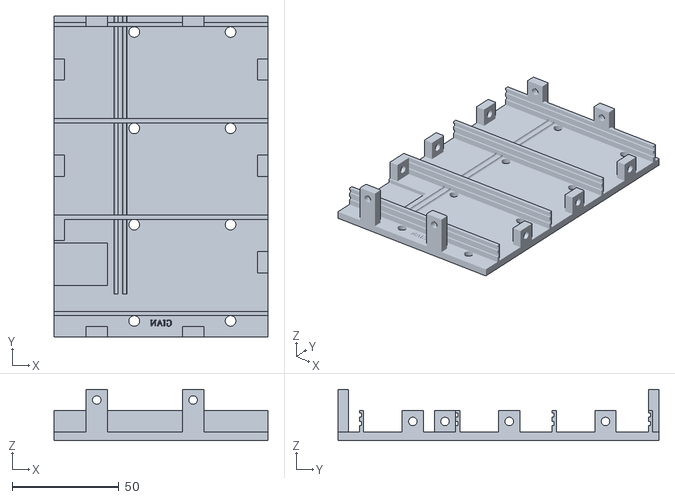
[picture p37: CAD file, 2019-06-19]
The Project/Research and Files/Files/Matrix/3D Models/Type2/LED BASE22.stl
100.0 x 150.0 x 24.0

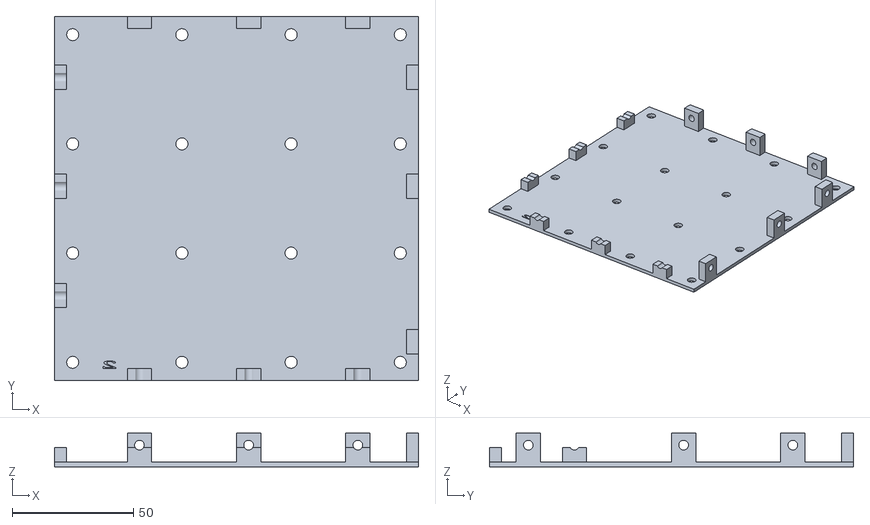
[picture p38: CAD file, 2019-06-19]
The Project/Research and Files/Files/Matrix/3D Models/Type2/Simplified/LED 21.stl
150.0 x 150.0 x 14.0

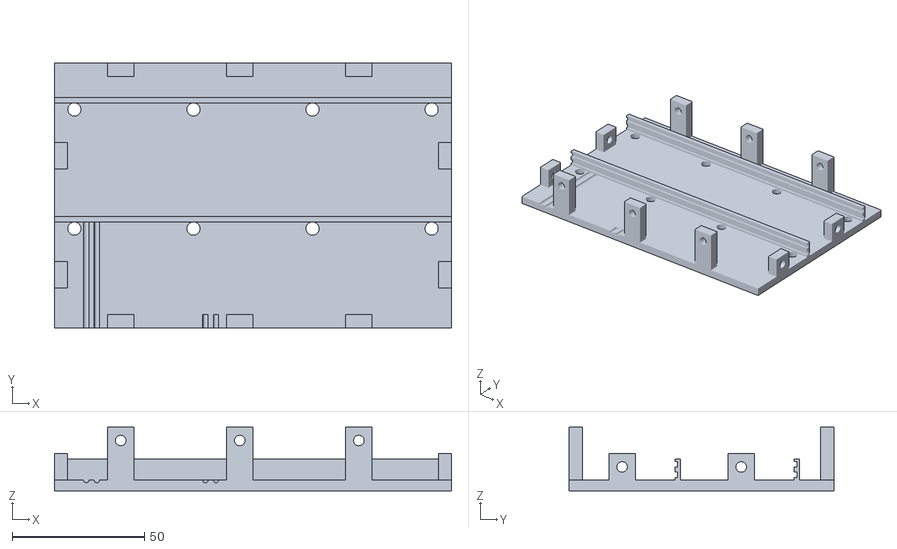
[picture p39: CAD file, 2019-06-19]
The Project/Research and Files/Files/Matrix/3D Models/Type1/LED BASE13.stl
150.0 x 100.0 x 24.0

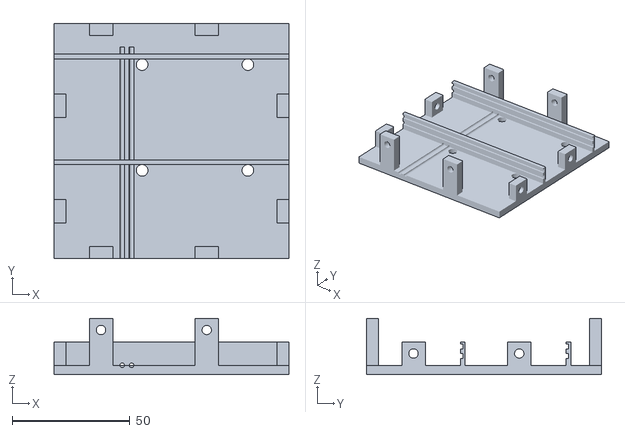
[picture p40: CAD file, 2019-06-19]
The Project/Research and Files/Files/Matrix/3D Models/Type2/LED BASE24.stl
100.0 x 100.0 x 24.0

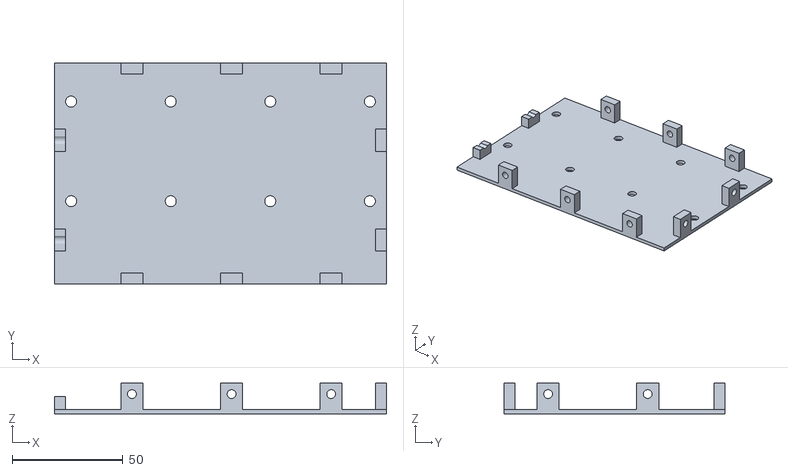
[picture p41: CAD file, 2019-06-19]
The Project/Research and Files/Files/Matrix/3D Models/Type2/Simplified/LED 23.stl
150.0 x 100.0 x 14.0

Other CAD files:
The Project/Research and Files/Files/Matrix/3D Models/Type2/Simplified/LED 24.stl
The Project/Research and Files/Files/Matrix/3D Models/Type2/LED BASE23.stl
The Project/Research and Files/Files/Matrix/3D Models/Type2/Simplified/LED 22.stl
The Project/Research and Files/Files/Matrix/3D Models/Type1/Simplified/LED 12.stl

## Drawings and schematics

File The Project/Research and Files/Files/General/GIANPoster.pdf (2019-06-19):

# General Interactive Automation Network

STUDENT GRIGORYAN VAHE | DR. MANOJ THAKUR SUPERVISOR

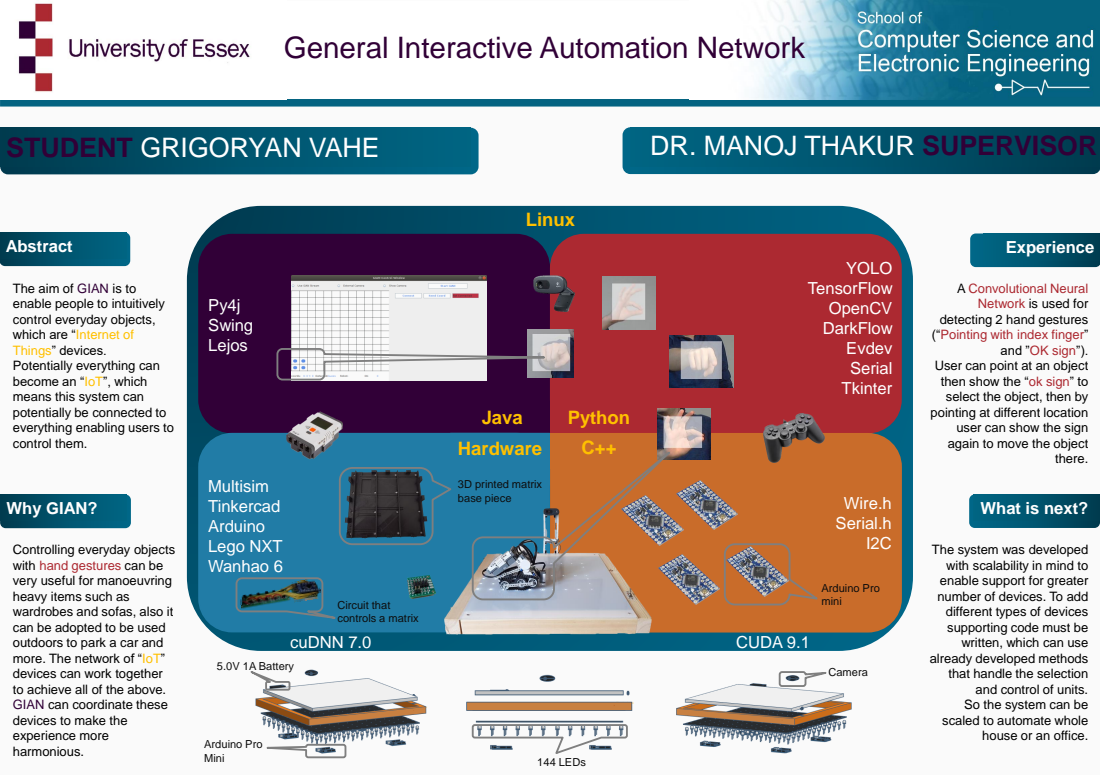
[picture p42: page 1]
Py4j Swing Lejos; YOLO TensorFlow OpenCV DarkFlow Evdev Serial Tkinter; Wire.h Serial.h I2C; Multisim Tinkercad Arduino Lego NXT Wanhao 6; Abstract; Why GIAN?; Experience; there.; Linux; Circuit that controls a matrix; Arduino Pro mini; 3D printed matrix base piece; Arduino Pro; Mini; 144 LEDs; Camera; cuDNN 7.0; CUDA 9.1; 5.0V 1A Battery

The aim of GIAN is to
enable people to intuitively
control everyday objects,
which are “Internet of
Things” devices.
Potentially everything can
become an “IoT”, which
means this system can
potentially be connected to
everything enabling users to
control them.

A Convolutional Neural
Network is used for

detecting 2 hand gestures
(“Pointing with index finger”

and ”OK sign”).

User can point at an object
then show the “ok sign” to
select the object, then by
pointing at different location
user can show the sign
again to move the object

Java | Python
Hardware | C++

What is next?

Controlling everyday objects
with hand gestures can be
very useful for manoeuvring
heavy items such as
wardrobes and sofas, also it
can be adopted to be used
outdoors to park a car and
more. The network of “IoT”
devices can work together
to achieve all of the above.
GIAN can coordinate these
devices to make the
experience more
harmonious.

The system was developed
with scalability in mind to
enable support for greater
number of devices. To add
different types of devices
supporting code must be
written, which can use
already developed methods
that handle the selection
and control of units.
So the system can be
scaled to automate whole

house or an office.

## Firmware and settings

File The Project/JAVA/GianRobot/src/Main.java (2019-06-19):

import lejos.nxt.*;
import lejos.nxt.comm.BTConnection;
import lejos.nxt.comm.Bluetooth;
import lejos.robotics.Color;
import lejos.robotics.localization.OdometryPoseProvider;
import lejos.robotics.navigation.DifferentialPilot;
import lejos.util.Stopwatch;

import java.io.BufferedReader;
import java.io.DataInputStream;
import java.io.DataOutputStream;
import java.io.InputStreamReader;
import java.util.*;

public class Main {
    public static final int[][] curCoord = {{7,2}};
    public static int[] newCoord={0,0};
    public static final int[] orientation = {3};
    public static final int[] options = {0};
    private static BTReceive bt;

    public static void main(String[] args){
        bt = new BTReceive();
        new Thread(bt).start();
        LCD.clear();
        System.out.println("Run< >Calibrate");
        while (true) {
            if (Button.RIGHT.isDown()) {
                LCD.clear(); System.out.println("Calibrate");
                new Calibrator();
//                break;
            }else if (Button.LEFT.isDown()){
                LCD.clear(); System.out.println("Running Default");
                startRobotDefault();

            }

            if(Button.ENTER.isDown()) System.exit(0);
        }
//        new Calibrator();
////        Button.waitForAnyPress();
    }

    private static void startRobotDefault() {
//        System.out.println("part 1");
        // def == 2.693943
        //4.2
        PathNavigator pn = new PathNavigator(2.693943f, 5.9f);
        PathPlanner pp = new PathPlanner();

        do {

            newCoord = bt.getCoord();
            synchronized (options){options[0] = newCoord[3];}

            if ((newCoord[0]!=curCoord[0][0] && newCoord[1]!=curCoord[0][1]) && (newCoord[0]!=0 && newCoord[1]!=0)) {
                System.out.println(curCoord[0][0] + ":" + curCoord[0][1] + "|" + newCoord[0] + ":" + newCoord[1]);
                pn.followPath(pp.getPlannedPath(curCoord[0], newCoord, orientation[0]));
                synchronized (curCoord){
                    curCoord[0] = new int[]{newCoord[0], newCoord[1]};
                }
            }

        } while (!Button.ENTER.isDown());

    }
}

/***********************************************************************************************************************
 *                                                  Calibrator                                                         *
 **********************************************************************************************************************/

class Calibrator{
    Thread LEDThread;
    public boolean StopThreads = false;
    private ColorSensor ledSens;

    public Calibrator(){
        ledSens = new ColorSensor(SensorPort.S1);
        ledSens.setFloodlight(false);

//        System.out.println(findWheelDiameter(15.0));
//        System.out.println(findTrackWidth((2.66470/2)/100));
//        Button.waitForAnyPress();

    }

    public double findWheelDiameter(double distance) {
        /*
            find wheel diameter
            D = Circumference/piHigh
            Circumference = Distance traveled / revolutions
            1 degree = 0.002778 revolutions
        */
        PathNavigator.moveForwardNoPilot(180); // 0.5 rpm  => 360 == 1 rpm
        int[] motorDgreeRevolutions = {0,0};
        while (!StopThreads) {
            try {
                if (ledSens.getRawLightValue() > 500) {
                    PathNavigator.stopMotors();
                    motorDgreeRevolutions = PathNavigator.getTacho();
                    System.out.println("Found "+motorDgreeRevolutions[0]+" : "+motorDgreeRevolutions[1]);
                    break;
                }
                Thread.sleep(1);
            } catch (InterruptedException e) {
                e.printStackTrace();
            }
        }

        double revolution = motorDgreeRevolutions[1]*0.002778;
        double circumference = distance/revolution;
        return circumference/Math.PI;
    }

    public double findTrackWidth(double wheelRadius) {
        /**
         * find track width  look robotics lab
         */
        long beginTime = System.currentTimeMillis();
        long elapsedTime = 0;
        PathNavigator.rotateLeftWheelNoPilot(360);
        int[] motorDgreeRevolutions = {0,0};
        while (!StopThreads) {
            try {
                motorDgreeRevolutions = PathNavigator.getTacho();
                if (ledSens.getRawLightValue() > 500) {
                    elapsedTime = (System.currentTimeMillis()-beginTime)/1000;
                    PathNavigator.stopMotors();
                    System.out.println("Found "+motorDgreeRevolutions[0]+" : "+Math.abs(motorDgreeRevolutions[1])+" : "+elapsedTime);
                    break;
                }
                Thread.sleep(1);
            } catch (InterruptedException e) {
                e.printStackTrace();
            }
        }
        double linearSpeed = wheelRadius*0.10472; // in m/s
        double distance = linearSpeed*elapsedTime; System.out.println("V="+linearSpeed+"\nS="+distance); // in meters
        System.out.println("exp="+((distance/Math.PI)*100)); // in cm
        double trackWidth = (2*Math.PI*distance)/(motorDgreeRevolutions[0]*0.002778);
        return trackWidth*200; // in cm
    }

    public void moveRobotWithIntervals(int sec){
        PathNavigator pn = new PathNavigator(2.693943f, 5.9f);
                try {
                    for (int i =1; i<=7; i++) {
                        pn.moveForward(i*2);
                        System.out.println("travled : "+(i*2)+" cm");
                        Thread.sleep(sec * 1000);
                    }
                }catch (Exception e){System.out.println(e.toString());}
    }
}


/***********************************************************************************************************************
 *                                                 Path Navigator                                                      *
 **********************************************************************************************************************/

class PathNavigator{
    private final DifferentialPilot pilot;
    private static NXTRegulatedMotor motorRight = Motor.C;
    private static NXTRegulatedMotor motorLeft = Motor.A;
    public boolean naviagate = true;
    private int[] tacho;

    public PathNavigator(float wheelDiameter, float trackWidth){
        pilot = new DifferentialPilot(wheelDiameter, trackWidth, motorRight, motorLeft);
        OdometryPoseProvider odometry = new OdometryPoseProvider(pilot);
        pilot.addMoveListener(odometry);
        odometry.moveStarted(null, pilot);
        pilot.setTravelSpeed(10);
        pilot.setRotateSpeed(50);
    }

    public void moveForward(double distance){
        pilot.travel(distance-findTravelOffSet(distance));
    }

    private double findTravelOffSet(double distance) {
//        (distance*0.2)-0.2)
//        (0.37661236750712285*distance)-0.9650401673818262
        /* a python script was written to find these numbers
            the numbers are calculated using linear function y = a * x - b
            where "a" and "b" are un-knows and are calculated
            "y" is the amount of error the robot makes when it travels "x" distance
         */
        if(distance<6) return (0.22041666666666662*distance)-0.20000000000000004;
        else return (0.22138888888888889*distance)-0.2000000000000001;
    }

    public void rotate(double degree){
        pilot.rotate(degree+findRotationOffSet(degree));
    }

    private double findRotationOffSet(double degree) {
        if (degree<0) return (0.5493*(degree+1))+0.5555;
        return (0.5493*(degree-1))+0.5555;
    }

    private static void resetTachos(){motorLeft.resetTachoCount();    motorRight.resetTachoCount();}

    public static void moveForwardNoPilot(int revolutions){
        resetTachos();
        motorLeft.setSpeed(revolutions);    motorRight.setSpeed(revolutions);
        motorLeft.forward();    motorRight.forward();
    }

    public static void rotateLeftWheelNoPilot(int revolutions) {
        resetTachos();
        motorLeft.setSpeed(revolutions);   // motorRight.setSpeed(revolutions);
        motorLeft.forward();    //motorRight.backward();
    }

    public static void stopMotors(){
        motorLeft.stop();  motorRight.stop();
    }

    public static int[] getTacho(){ // degrees turned
        return new int[]{motorLeft.getTachoCount(), motorRight.getTachoCount()};
    }



    public void followPath(List<double[]> path) {
        /*
         * int[0] := 1 || 0
         * 0= rotate
         * 1= travel
         */
        for (double[] i : path){
            if (i.length == 2){
                if (i[0] == 0) rotate(i[1]);
                else if (i[0]==1) moveForward(i[1]);
            }
        }
    }
}

/***********************************************************************************************************************
 *                                                 Path Planner                                                        *
 **********************************************************************************************************************/

class PathPlanner{
    private Map<Integer, Integer> orientationToDegree = new HashMap<Integer, Integer>();

    public PathPlanner(){
        populateOrientationMap();
    }

    private void populateOrientationMap() {
        orientationToDegree.put(1,0);
        orientationToDegree.put(2,180);
        orientationToDegree.put(3, -90);
        orientationToDegree.put(4,90);
    }

    public List<double[]> getPlannedPath(int[] curPos, int[] destination, int orientation){
        List<double[]> instructions = new LinkedList<double[]>();
        /*
         * info 'orientation'
         * 1=North
         * 2=South
         * 3=West
         * 4=East
         */

        if (destination[1] > curPos[1]){
            instructions = planFromSouthToNorth(curPos, destination, orientation);
        }else if (destination[1]<curPos[1]){
            // plan from the other side of the frame
            instructions = planFromNorthToSouth(curPos, destination, orientation);
        }

        return instructions;
    }

    private List<double[]> planFromNorthToSouth(int[] curPos, int[] destination, int orientation) {
        System.out.println("North->South");
        List<double[]> instructions = new LinkedList<double[]>();

        // set orientation towards SOUTH
        if(orientationToDegree.get(orientation) != 0) {
            instructions.add(new double[]{0, (orientationToDegree.get(orientation))});
            synchronized (Main.orientation) {
                Main.orientation[0] = orientation;
            }
        } else {
            instructions.add(new double[]{0, 180});
            synchronized (Main.orientation) {
                Main.orientation[0] = 2;
            }
        }

        // Cover The Y distance
        if (orientationToDegree.get(orientation) == 0){
            double y = ((destination[1] - curPos[1])+2) * -4.5;
            instructions.add(new double[]{1, y});
        }else {
            double y = (destination[1] - curPos[1]) * -4.5;
            instructions.add(new double[]{1, y});
        }

        System.out.println(destination[0]+" : "+curPos[0]);
        // set orientation towards destination
        if(destination[0] > curPos[0]) { // go  west
            instructions.add(new double[]{0, orientationToDegree.get(3)});
            synchronized (Main.orientation) {
                Main.orientation[0] = 4;
            }
        }else if (destination[0] < curPos[0]) { // go east
            instructions.add(new double[]{0, orientationToDegree.get(4)});
            synchronized (Main.orientation) {
                Main.orientation[0] = 3;
            }
        }

        // drive to the destination
        double x = ((destination[0] - curPos[0]));
        // drive to destination
        if(x<0){ // robot made a turn to west
            if(orientationToDegree.get(orientation)==0) instructions.add(new double[]{1, -4.5*(x+2)}); // robot skips 2 steps if it was position towards north initially
            else if (orientationToDegree.get(orientation)==90) instructions.add(new double[]{1, -4.5*(x+4)}); // 4 steps for west
            else if (orientationToDegree.get(orientation)==-90) instructions.add(new double[]{1, -4.5*x}); // no skip for east
        }else if (x>0){ // robot made turn to east
            if(orientationToDegree.get(orientation)==0) instructions.add(new double[]{1, 4.5*(x-2)});
            else if (orientationToDegree.get(orientation)==90) instructions.add(new double[]{1, 4.5*(x)});
            else if (orientationToDegree.get(orientation)==-90) instructions.add(new double[]{1, 4.5*(x-4)});
        }

        return instructions;
    }
/*
*
*
*
* */
    private List<double[]> planFromSouthToNorth(int[] curPos, int[] destination, int orientation) {
        System.out.println("South->North");
        List<double[]> instructions = new LinkedList<double[]>();

        // set orientation towards NORTH
        if(orientationToDegree.get(orientation) != 180) {
            instructions.add(new double[]{0, (-1 * orientationToDegree.get(orientation))});
            synchronized (Main.orientation) {
                Main.orientation[0] = 2;
            }
        }

        // Cover The Y distance
        if (orientationToDegree.get(orientation) == 180){
            double y = ((destination[1] - curPos[1])-2) * 4.5;
            instructions.add(new double[]{1, y});
        }else {
            double y = (destination[1] - curPos[1]) * 4.5;
            instructions.add(new double[]{1, y});
        }

        System.out.println(destination[0]+" : "+destination[1]);
        // set orientation towards destination
        if(destination[0] < curPos[0]) { // go  west
            instructions.add(new double[]{0, orientationToDegree.get(3)});
            synchronized (Main.orientation) {
                Main.orientation[0] = 3;
            }
        }else if (destination[0] > curPos[0]) { // go east
            instructions.add(new double[]{0, orientationToDegree.get(4)});
            synchronized (Main.orientation) {
                Main.orientation[0] = 4;
            }
        }

        // drive to the destination
        double x = ((destination[0] - curPos[0]));

        // drive to destination
        if(x<0){ // robot is pointing towards west
            if(orientationToDegree.get(orientation)==180) instructions.add(new double[]{1, -4.5*(x+2)});
            else if (orientationToDegree.get(orientation)==90) instructions.add(new double[]{1, -4.5*(x+4)});
            else if (orientationToDegree.get(orientation)==-90) instructions.add(new double[]{1, -4.5*x});
        }else if (x>0){ // robot is pointing towards east
            if(orientationToDegree.get(orientation)==180) instructions.add(new double[]{1, 4.5*(x-2)});
            else if (orientationToDegree.get(orientation)==90) instructions.add(new double[]{1, 4.5*(x)});
            else if (orientationToDegree.get(orientation)==-90) instructions.add(new double[]{1, 4.5*(x-4)});
        }

        return instructions;
    }
}

/***********************************************************************************************************************
 *                                             Bluetooth communicator                                                  *
 **********************************************************************************************************************/

class BTReceive implements Runnable {
    private DataOutputStream dos;
    private BTConnection connection;
    public boolean communicate = true;
    private DataInputStream dis;
    public final int[][] coords = new int[1][4];

    public BTReceive(){
        String connected = "Connected";
        String waiting = "Waiting...";
        String closing = "Closing...";

        System.out.println(waiting);
        connection = Bluetooth.waitForConnection();
        dis = connection.openDataInputStream();
        dos = connection.openDataOutputStream();

        System.out.println(connected);
        Sound.beep();


    }

    public int[] getCoord(){
        synchronized (coords){
            return coords[0];
        }
    }

    @Override
    public void run() {
        int[] coord = {0,0,0,0};
        boolean isBipped = false;
        while (communicate) {

            try {
                synchronized (Main.curCoord) {
                    for (int i : Main.curCoord[0]) {
                        dos.writeInt(i);
                    }
                }

                synchronized (Main.orientation){
                    dos.writeInt(Main.orientation[0]);
                }

                synchronized (Main.options){
                    dos.writeInt(Main.options[0]);
                }

                dos.flush();


                for (int i = 0; i < 4; i++) {
                    coord[i] = dis.readInt();
                }

                if (coord[3]==4 && !isBipped){
                    Sound.beep();
                    isBipped = true;
                }else if(coord[3] != 4) {
                    isBipped = false;
                }

                synchronized (coords) {
                    if (coord[0]!=coords[0][0] || coord[1]!= coords[0][1]) {
                        coords[0] = coord;
                        System.out.println(coord[0] + " :: " + coord[1]);
                    }
                }

                Thread.sleep(100);

//                dos.close();
            }catch (Exception e){}


        }

        try {
            dis.close();
            dos.close();
            connection.close();
//            LCD.clear();
        }catch (Exception e){}
    }

    private void communicateWithPython(DataInputStream dis, DataOutputStream dos, int[] coord) {
        String dataToSend = ":";

        synchronized (Main.curCoord){
            for (int i : Main.curCoord[0]) {
                dataToSend+=i;
                dataToSend+=",";
            }
        }


        synchronized (Main.orientation){dataToSend+=Main.orientation[0]; dataToSend+=",";}
        synchronized (Main.options){dataToSend+=Main.options[0];}

        try {
            dos.writeBytes(dataToSend);
            dos.flush();
            Thread.sleep(100);
        }catch (Exception e){}


        try {
            System.out.println("to receive");

            String receivedData = dis.readLine();
//                dis.wait(100);
                System.out.println("received: "+receivedData);


                boolean firstNumber = true;
                String firstNum = "";
                String secondNum = "";
                for (char c : receivedData.toCharArray()) {
                    if (c != ',' && firstNumber) {
                        firstNum += c;
                    } else if (c == ',' && firstNumber) {
                        firstNumber = false;
                        continue;
                    } else {
                        secondNum += c;
                    }
                }

                coord[0] = Integer.parseInt(firstNum);
                coord[1] = Integer.parseInt(secondNum);
                synchronized (coords) {
                    if (!Arrays.equals(coord, coords[0])) {
                        coords[0] = coord;
                        System.out.println(coord[0] + " :: " + coord[1]);
                    }
                }

        }catch (Exception e){
//            System.out.println(e+"");
            }
    }

}

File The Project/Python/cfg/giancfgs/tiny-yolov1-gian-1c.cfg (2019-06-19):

[net]
batch=64
subdivisions=2
height=448
width=448
channels=3
momentum=0.9
decay=0.0005

saturation=.75
exposure=.75
hue = .1

learning_rate=0.0005
policy=steps
steps=200,400,600,800,20000,30000
scales=2.5,2,2,2,.1,.1
max_batches = 40000

[convolutional]
batch_normalize=1
filters=16
size=3
stride=1
pad=1
activation=leaky

[maxpool]
size=2
stride=2

[convolutional]
batch_normalize=1
filters=32
size=3
stride=1
pad=1
activation=leaky

[maxpool]
size=2
stride=2

[convolutional]
batch_normalize=1
filters=64
size=3
stride=1
pad=1
activation=leaky

[maxpool]
size=2
stride=2

[convolutional]
batch_normalize=1
filters=128
size=3
stride=1
pad=1
activation=leaky

[maxpool]
size=2
stride=2

[convolutional]
batch_normalize=1
filters=256
size=3
stride=1
pad=1
activation=leaky

[maxpool]
size=2
stride=2

[convolutional]
batch_normalize=1
filters=512
size=3
stride=1
pad=1
activation=leaky

[maxpool]
size=2
stride=2

[convolutional]
batch_normalize=1
size=3
stride=1
pad=1
filters=1024
activation=leaky

[convolutional]
batch_normalize=1
size=3
stride=1
pad=1
filters=30
activation=leaky

[connected]
output= 1470
activation=linear

[detection]
classes=1
coords=4
rescore=1
side=7
num=2
softmax=0
sqrt=1
jitter=.2

object_scale=1
noobject_scale=.5
class_scale=1
coord_scale=5

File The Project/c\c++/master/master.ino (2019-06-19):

#include <Wire.h>
#include <math.h>
const int deltimeon = 1;
const int deltimeoff = 0;
const char rowsp[]= {8,9,13,12,11,10};
const char rowsn[]= {7,6,5,4,3,2};
int SentMessage[4];
int l = 0;
int r = 0;
int showFor = 50;

/*************************************************************
 *                          Setup                            *
 *************************************************************/

void setup() {
  Serial.begin(9600);
  openI2C();
//  Wire.onReceive(receiveCoords);
  setPinModes();  
  litTheMatrix();
  showG(3,3,showFor);
  showI(3,3,showFor);
  showA(3,3,showFor);
  showN(3,3,showFor);
  showRobotInitLoc();
  Wire.flush();

}

void setPinModes(){
  for(int i = 0; i<6; i++){
    pinMode(rowsp[i], OUTPUT);
    pinMode(rowsn[i], OUTPUT);  
  }
}

void showG(int x, int y, int leveON){
  int coords[][2] = {{x+3,y+3},{x+4,y+3},{x+5,y+3},
                      {x+6,y+3},{x+6,y+2},{x+6,y+1},
                      {x+6,y+0},{x+5,y+0},{x+4,y+0},
                      {x+3,y+0},{x+2,y+0},{x+1,y+0},
                      {x+0,y+0},{x+0,y+1},{x+0,y+2},
                      {x+0,y+3},{x+0,y+4},{x+0,y+5},
                      {x+0,y+6},{x+1,y+6},{x+2,y+6},
                      {x+3,y+6},{x+4,y+6},{x+5,y+6},
                      {x+6,y+6},{x+6,y+5}};
  for(int t = 0; t<leveON; t++){
    for(int i =0; i< 26; i++){
      showLoc(coords[i][0], coords[i][1]);
    }
  }
}

void showI(int x, int y, int leveON){
  int coords[][2] = {{x+0,y+0},{x+1,y+0},{x+2,y+0},
                      {x+3,y+0},{x+4,y+0},{x+5,y+0},
                      {x+6,y+0},{x+0,y+1},{x+1,y+1},
                      {x+2,y+1},{x+3,y+1},{x+4,y+1},
                      {x+5,y+1},{x+6,y+1},{x+3,y+2},
                      {x+3,y+3},{x+3,y+4},{x+3,y+5},
                      {x+3,y+6},{x+0,y+6},{x+1,y+6},
                      {x+2,y+6},{x+4,y+6},{x+5,y+6},
                      {x+6,y+6},{x+0,y+5},{x+1,y+5},
                      {x+2,y+5},{x+4,y+5},{x+5,y+5},
                      {x+6,y+5}};
  for(int t = 0; t<leveON; t++){
    for(int i =0; i< 31; i++){
      showLoc(coords[i][0], coords[i][1]);
    }
  }
}

void showA(int x, int y, int leveON){
  int coords[][2] = {{x+3,y+6},{x+2,y+6},{x+4,y+6},
                      {x+1,y+2},{x+2,y+2},{x+3,y+2},
                      {x+4,y+2},{x+5,y+2},
                      {x+0,y+0},{x+6,y+0},{x+2,y+4},
                      {x+4,y+4}};
  for(int t = 0; t<leveON; t++){
    for(int i =0; i< 13; i++){
      showLoc(coords[i][0], coords[i][1]);
    }
  }
}

void showN(int x, int y, int leveON){
  int coords[][2] = {{x+0,y+6},{x+6,y+0},{x+3,y+3},
                      {x+4,y+2},{x+5,y+1},{x+2,y+4},
                      {x+1,y+5},{x+0,y+1},{x+0,y+2},
                      {x+0,y+3},{x+0,y+4},{x+0,y+5},
                      {x+0,y+6},{x+0,y+0},{x+6,y+0},
                      {x+6,y+1},{x+6,y+2},{x+6,y+3},
                      {x+6,y+4},{x+6,y+5},{x+6,y+6},
                      };
  for(int t = 0; t<leveON; t++){
    for(int i =0; i< 21; i++){
      showLoc(coords[i][0], coords[i][1]);
    }
  }
}

/*************************************************************
 *                        Communication                      *
 *************************************************************/

void loop() {
  for(int i=0; i<4 ;i++){
    if(Serial.available()){
      SentMessage[i] = Serial.read();
    }
  }

  delay(10);
  Serial.print(SentMessage[0]);
  Serial.print(SentMessage[1]);
  Serial.print(SentMessage[2]);
  Serial.println(SentMessage[3]);
  Serial.flush();
  Wire.flush();

  showCoords(SentMessage[0], SentMessage[1], SentMessage[2], SentMessage[3]);
  
  
  delayMicroseconds(350);
//  openI2C();
}

/*************************************************************
 *                         Matrix Control                    *
 *************************************************************/

void allLEDsOFF(){
  for(int i = 0; i<6; i++){
    digitalWrite(rowsn[i], LOW);
    digitalWrite(rowsp[i],HIGH); 
  }
}

void showLoc(int x, int y){
  broadcast(x, y); 
  if(SentMessage[0]<6 && SentMessage[1]<6){
    allLEDsOFF();
    digitalWrite(rowsp[x], LOW);
    digitalWrite(rowsn[y], HIGH);
  }else{
    allLEDsOFF();
  }
}

void showFingerLoc(int x, int y){
  if(x>10 && y>10){showFingerLoc(x-1, y-1);} 
  else if(x<10 && y>10){showFingerLoc(x, y-1);} 
  else if(x>10 && y<10){showFingerLoc(x-1, y);}
  else{ 
    showLoc(x,y);
    showLoc(x,y+1);
    showLoc(x+1,y);
    showLoc(x+1,y+1);
  }
}

void showRobotLoc(int x, int y, int o){
  if(o==1){showRobotNorth(x,y);}
  else if(o==2){showRobotSouth(x,y);}
  else if(o==3){showRobotWest(x,y);}
  else if(o==4){showRobotEast(x,y);}
}

void showRobotNorth(int x,int y){
   if(x==0){showRobotNorth(x+1, y);}
   else if(x>10){showRobotNorth(x-1,y);}
   else if(y<3){showRobotNorth(x,y+(3-y));}
   else if(y>11){showRobotNorth(x,y-1);}
   else{
    showLoc(x,y);
    showLoc(x+1,y);
    showLoc(x-1,y);
    showLoc(x,y-3);
    showLoc(x+1,y-3);
    showLoc(x-1,y-3);
    showLoc(x+1,y-1);
    showLoc(x-1,y-1);
    showLoc(x+1,y-2);
    showLoc(x-1,y-2);
   }
}

void showRobotSouth(int x,int y){
  if(x==0){showRobotSouth(x+1, y);}
   else if(x>10){showRobotSouth(x-1,y);}
   else if(y>8){showRobotSouth(x,y-(y-8));}
//   else if(y>10){showRobotSouth(x,y-1);}
   else{
    showLoc(x,y);
    showLoc(x+1,y);
    showLoc(x-1,y);
    showLoc(x,y+3);
    showLoc(x+1,y+3);
    showLoc(x-1,y+3);
    showLoc(x+1,y+1);
    showLoc(x-1,y+1);
    showLoc(x+1,y+2);
    showLoc(x-1,y+2);
   }
}
void showRobotWest(int x,int y){
  if(x>8){showRobotWest(x-(x-8),y);}
//   else if(x>10){showRobotWest(x-1,y);}
   else if(y==0){showRobotWest(x,y+1);}
   else if(y>10){showRobotWest(x,y-1);}
   else{
    showLoc(x,y);
    showLoc(x,y+1);
    showLoc(x,y-1);
    showLoc(x+3,y);
    showLoc(x+3,y+1);
    showLoc(x+3,y-1);
    showLoc(x+1,y+1);
    showLoc(x+1,y-1);
    showLoc(x+2,y+1);
    showLoc(x+2,y-1);
   }
}
void showRobotEast(int x,int y){
  if(x<3){showRobotEast(x+(3-x),y);}
   else if(x>11){showRobotEast(x-1,y);}
   else if(y==0){showRobotEast(x,y+1);}
   else if(y>10){showRobotEast(x,y-1);}
   else{
    showLoc(x,y);
    showLoc(x,y+1);
    showLoc(x,y-1);
    showLoc(x-3,y);
    showLoc(x-3,y+1);
    showLoc(x-3,y-1);
    showLoc(x-1,y+1);
    showLoc(x-1,y-1);
    showLoc(x-2,y+1);
    showLoc(x-2,y-1);
   }
}

void showCoords(int x, int y, int o, int op){
  if (o==0){ showFingerLoc(x,y);}
  if (o!=0){showRobotLoc(x,y,o);}
  else if (op==4){showRobotLoc(x,y,o);}
}

/*************************************************************
 *               Use for checking states of LEDs             *
 *************************************************************/

void showRobotInitLoc(){
  for (int i=0; i<800; i++){
    showRobotLoc(7,2,3);
  }
}
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

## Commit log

2019-06-19 GIAN init
    [LED 12.stl, LED 13.stl, LED 14.stl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]
2020-05-08 dir struct. fix
    [LED 12.stl, LED 13.stl, LED 14.stl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]
2020-05-08 rm gian dir
    [LED 12.stl, LED 13.stl, LED 14.stl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]
